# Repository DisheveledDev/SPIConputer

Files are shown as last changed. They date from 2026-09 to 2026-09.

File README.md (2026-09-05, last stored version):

# SPIConputer (working title)

> A retro computer whose system bus is SPI. Every peripheral is an
> autonomous node with its own microcontroller; the main CPU sends it a
> command and the node carries it out without further CPU involvement.

## Status

Design phase. Nothing is built yet. This README is the living design
document: decisions go in the [Decision log](#decision-log), unresolved
items live in [Open questions](#open-questions).

## Concept

- **Bus = SPI.** SCK, MOSI and MISO are shared across all nodes; each
  node gets its own chip-select (SS) line from the main CPU.
- **Autonomous peripherals.** Each node (video, storage, IO, sound,
  console) has its own MCU (ATmega328 or similar). The main CPU issues
  high-level commands ("draw this sprite", "read sector N", "play this
  note") and moves on. Nodes report completion asynchronously.
- **C64 form factor.** The board fits inside a Commodore 64 shell,
  reusing its keyboard and (ideally) its port cutouts.

## Architecture overview

```
                                  +----------------------+
                                  |  MAIN CPU (master)   |
                                  |  MCU: TBD            |
                                  +--+--+--+--+--+--+----+
                                     |  |  |  |  |  |
        Bus: SCK + MOSI + MISO shared; one SS per node; IRQ per node (TBD)
                                     |  |  |  |  |  |
        +----------------------------+  |  |  |  |  +--------------------------+
        |                               |  |  |  |                             |
  +-----+--------+              +-------+  |  |  +-------+             +-------+--------+
  | VIDEO NODE   |              | IO NODE |  |  | STORAGE |             | SOUND NODE     |
  | ATmega2560   |              | ATmega  |  |  | NODE    |             | ATmega328 (TBD)|
  +-----+--------+              +---+-----+  |  +----+----+             +-------+--------+
        |                           |        |       |                         |
  2nd SPI -> Flash           C64 keyboard    |   SD card (SPI)           Audio out (TBD)
  (tile/glyph data)          Joystick x2     |
        |                           |        |
       VGA (DB15)                   |        |
                                    |   +----+--------+
                                    |   | CONSOLE NODE |
                                    |   | RS232 / TBD  |
                                    |   +-------------+
                                    |
                          +---------+---------+
                          | EXPANSION (SDI)   |
                          | bus passthrough   |
                          +-------------------+
```

## System bus

### Signals

| Signal | Direction | Notes |
| --- | --- | ----- |
| SCK | master -> all | Bus clock |
| MOSI | master -> all | Master out, slave in |
| MISO | all -> master | Shared; slaves tri-state when not selected |
| SS_n | master -> one node each | Dedicated chip-select per node |
| IRQ_n  | node -> master | Async completion signal (scheme TBD) |

### Protocol (proposal, unverified)

- Every transaction: master asserts the node's SS, sends a 1-byte
  command, an optional length byte, then payload. The slave responds
  with status byte(s) in the same transfer.
- Each node exposes a small **register map**: writing a command
  register starts an autonomous operation; a status register reports
  idle/busy/done/error; data registers move payloads.
- Completion: node asserts IRQ_n when done (or master polls status).
  See [Open questions](#open-questions).

### Timing and electrical gotchas

- **Slave clock limit:** on classic AVRs, SPI *slave* mode tops out at
  Fosc/4 (4 MHz at 16 MHz Fosc) even though *master* mode can run at
  Fosc/2 (8 MHz). The bus clock is therefore realistically **4 MHz**
  unless a node runs a faster crystal or a different SPI peripheral.
- **Shared MISO:** AVR SPI hardware tri-states MISO while SS is
  deasserted, which is what makes the shared bus work. Firmware must
  keep the SPI peripheral in slave mode; don't reuse MISO as a GPIO
  output.
- **Master SS pin:** in AVR SPI master mode the SS pin must be an
  output (or held high) or the master's own SPI can drop into slave
  mode on a false edge.
- Keep traces short; bus speed is modest but the bus crosses multiple
  boards/connectors.

## Nodes

### Main CPU (master)

- MCU: **TBD**. Candidates: ATmega2560 (fits the all-AVR theme and has
  enough pins for per-node SS + IRQ), or something bigger.
- Owns the bus, dispatches commands, runs the OS/shell/BASIC.
- Needs enough GPIO for: one SS per node, one IRQ per node, any
  console-side RS232 if not handled by a node.

### Video node

- MCU: **ATmega2560-16AU** (specified).
- Output: **VGA via DB15** (rear panel).
- Rendering: **text/sprite system**. Tile map and sprite list live in
  SRAM; tile/glyph bitmaps live in an external **SPI flash** on a
  *second* SPI bus (separate from the system bus).
- Firmware renders scanlines, not a CPU-driven framebuffer.

**Timing budget** (this constrains every video decision):

- Pixel clock comes from an AVR shift register (SPI/USART in master
  mode) = Fosc/2 = **8 MHz** at 16 MHz Fosc.
- One VGA line (31.78 µs) = ~254 pixel clocks at 8 MHz, so visible
  width is roughly **160-250 px** at 1 bit per pixel, packed 8 px per
  byte (~25-30 bytes per line, ~1 µs per byte shifted out).
- Flash reads also max out at ~1 byte/µs (8 MHz SPI). Fetching tile
  data on the fly leaves zero slack, so glyphs/tile rows must be
  **cached into SRAM during blanking** (8 KB SRAM on the 2560).
- Resolutions, colour depth (e.g. 3-bit RGB via 3 pins vs. resistor
  DAC) and sprite count are all [open questions](#open-questions).

### IO node

- MCU: ATmega328 or similar.
- Drives the **C64 keyboard** (8x8 matrix, needs 16 GPIOs + pull-ups)
  via the internal connector, and two **DB9 joystick ports**
  (Atari/C64 standard: 4 directions + fire, active-low, pulled high).
- Scans/debounces locally; the main CPU reads key/joystick *events*,
  not raw matrix state.

### Storage node

- MCU: ATmega328 or similar.
- **SD card in SPI mode** (rear panel slot).
- Exposes block read/write; FAT layer either here or on the main CPU.
- Gotcha: SD cards are **3.3 V logic** — the node needs a 3.3 V rail
  (LDO) and level shifting on MOSI/SCK/SS (MISO can usually feed 5 V
  inputs directly through a divider). Classic AVRs are 5 V parts.

### Console node

- **RS232** serial console (rear panel, DB9).
- Open: true RS232 levels (needs a MAX232-style transceiver) vs. TTL
  serial vs. USB (FTDI/CH340). This node may end up merged into the IO
  node.

### Sound node

- MCU: ATmega328 or similar (TBD).
- Receives note/effect commands and generates audio autonomously;
  output via PWM + RC filter, then amp/jack (TBD).
- Open: chiptune-style synth, sample playback, or a SID-inspired voice
  set.

### Expansion (SDI)

- Rear-panel expansion connector. Intended as a passthrough of the
  system bus (SCK/MOSI/MISO + an SS/IRQ pair + power) so new nodes can
  hang off the bus.
- **"SDI" needs defining** — see [Open questions](#open-questions).

## Connectors

| Connector | Location | Standard / notes |
| --- | --- | --- |
| VGA | rear | DB15, driven by video node |
| Console | rear | DB9 RS232 (or USB) — TBD |
| Expansion | rear | SDI — bus passthrough, pinout TBD |
| SD card | rear/side | microSD slot, SPI mode |
| Joystick x2 | rear/side | DB9, Atari/C64 standard |
| Keyboard  | internal | C64 keyboard connector, matrix scan by IO node |
| Power | rear | 5 V barrel jack — TBD |

## Form factor

- Board must fit a **C64 shell**; port cutouts should line up with the
  case openings. Open: which C64 revision (breadbin vs. 64C) — they
  have different keyboard connectors and cutouts.

## Power

- Single **5 V** rail for all nodes; local 3.3 V LDO on the storage
  node (and anywhere else 3.3 V logic appears). Total draw is small
  (a handful of AVRs + flash + SD), but budget should be verified once
  nodes are prototyped.

## Firmware conventions (proposed)

- Every node: **command loop** — SPI slave ISR receives command frames,
  main loop executes the current task, sets status, raises IRQ.
- Shared node firmware skeleton/library would avoid re-implementing the
  bus layer per node (TBD once toolchain is chosen).
- Each board exposes an **ICSP/ISP header** for initial programming
  and bootloader flashing.

## Development tooling

TBD. Candidates: avr-gcc + avrdude directly, PlatformIO, or Arduino
CLI. Decide in the [Decision log](#decision-log) and document the
canonical build/flash commands here once real code exists.

## Decision log

| # | Decision | Rationale | Date |
| - | --- | --- | ---- |
| | *(none yet)* |  |  |

## Open questions

1. **Main CPU** — which MCU drives the bus and runs the OS?
2. **Bus protocol** — exact command framing; register-map layout per
   node; IRQ scheme (one line per node vs. shared open-collector).
3. **Video modes** — target resolution(s), colour depth, sprite count,
   tile cache strategy within the 8 MHz pixel-clock budget.
4. **SDI definition** — what exactly does the expansion connector
   carry, and what can plug into it?
5. **Sound architecture** — synth vs. samples, voice count, output
   stage (amp, jack on case?).
6. **Console** — true RS232 levels, TTL, or USB?
7. **C64 case revision** — breadbin or 64C (keyboard connector,
   cutouts, mounting holes differ).
8. **Toolchain** — avr-gcc / PlatformIO / Arduino, and the flash
   workflow for each node.
9. **Firmware framework** — shared bus-layer library across nodes, or
   per-node implementations?

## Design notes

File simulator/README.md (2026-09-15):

# SPIComputer OS — Desktop Simulator

Lives next to `system/` (it is not part of the system itself).
Runs the real OS C code on macOS with the hardware layers replaced by
desktop implementations, so programs can be developed and tested without
the board:

| OS component | Simulator replacement |
|---|---|
| Core 0 FatFs / SD card (`fs_core0.c`) | `sim_fs.c`: a real host folder (default `./sdcard`) via stdio/POSIX |
| Core 0 HSTX/HDMI rendering | `render_line()` → RGB24 texture in an SDL window |
| Core 0 HDMI audio islands | `audio_mix()` → `SDL_QueueAudio` at 44.1 kHz stereo |
| Keyboard matrix / joysticks | SDL keyboard + game controllers → `input_event_t` queue |
| Two cores | one thread: scheduler steps with the RPC serviced inline |

The Lua core, process model, timers, input deposit, screen/sound/sys
modules, RPC transport and filesystem bridge are the actual OS sources
(the same ones the host tests exercise).

## Build & run

Requires SDL2. Run these commands from the folder that contains `system/`
and `simulator/`:

```bash
brew install sdl2
cmake -S simulator -B simulator/build
cmake --build simulator/build
./simulator/build/spicomputer_sim
```

On first run the simulator creates `sdcard/` **next to the simulator
binary** (e.g. `simulator/build/sdcard`) if it is missing, including the
protected `core/`, installed-app `apps/`, and writable `data/` directories.
Copy system programs into `core/`, applications into `apps/`, and user files
into `data/`. Basing it on the executable keeps it the same folder however
you launch the simulator; `--sdcard DIR` points it elsewhere.

With a `boot.lua` or `boot.prg` that starts the shell you land at the SPIOS
`READY.` prompt; `--boot <program>` boots a source or compiled program directly instead.

## Controls

| Input | Sends |
|---|---|
| Letters, digits, punctuation, Return, Tab, Backspace, Escape, Delete | ASCII key events (shift-aware) |
| Arrow keys, Home, F1–F7 | extended C64 key codes (`INPUT_KEY_*`) |
| F8 | RESTORE modifier |
| F9 | RUN/STOP |
| Left Alt | Commodore (C=) modifier |
| Numpad 8/2/4/6, 0 | joystick 1 (up/left/right/down, fire) |
| Game controllers | joystick 1 and 2 (d-pad + A/B fire) |

The simulator window is resizable. Its 640x480 output is always presented at
4:3, with letterboxing when the window shape is wider or taller. This makes
80-column text readable at larger window sizes without changing the logical
screen geometry.

## Options

```
--sdcard DIR        virtual SD card folder (default: <simulator dir>/sdcard)
--boot FILE         program to boot (default: core/boot.lua)
--ticks N           at most N scheduler ticks per frame (default: 64)
--dump-frame FILE   write the final 640x480 frame as a PPM
--dump-text FILE    write the final text screen (40x30, or 80x60 in modes 2/3), overlay
                    on top, '#' for non-ASCII codes, '|' then '^' under inverted cells
--wav FILE          headless: write the run's mixed audio as a 44.1 kHz stereo WAV
                    (one 60 Hz frame of samples per simulator frame)
--check FILE        compile FILE with the OS Lua and exit
--compile IN OUT    compile Lua source IN to a .prg binary chunk and exit
--strip             with --compile: leave out debug info (line numbers, local
                    names); the loaded program needs about a fifth less heap,
                    but its runtime errors carry no line numbers
--headless          no window/audio (smoke tests, CI)
--exit-after-ms N   quit automatically after N ms
--type TEXT         scripted keystrokes, one per frame (\n Return, \t Tab,
                    \e Esc, \u \d \l \r cursor keys, \1..\7 F1..F7, \w a
                    half-second pause, \\ backslash)
--type-delay-ms N   wait N ms after start before typing (default 500;
                    use ~3500 to type into the shell after the boot splash)
```

`--headless --exit-after-ms 1500` boots the OS, runs the scheduler and
the RPC, prints a summary and exits 0 — useful as a smoke test.
`--boot apps/foo.prg` starts a program directly instead of
`core/boot.lua` (the IDE uses this to run a project straight from its
folder, and `--boot core/os.prg` skips straight to the shell).
`--dump-frame shot.ppm` captures the last rendered frame for inspection
(convert with `sips -s format png shot.ppm --out shot.png`).

## Working on programs

Programs are ordinary files in `sdcard/`; source programs use `.lua` and
compiled Lua chunks use `.prg`. A program is loaded when launched (`run
foo` from a shell, or just `foo`), with the compiled `.prg` preferred when
both forms exist. Use `--compile source.lua output.prg` to create a chunk;
changes are picked up on the next launch;
`boot.lua` is read at startup. A program that saves files writes
straight back into the folder. In this workspace the card programs are
SPIEdit projects under `software/`; their builds (`software/*.lua`) are
what you copy into `sdcard/`.

## Behaviour notes

- Each rendered frame runs up to `--ticks` scheduler steps (default 64)
  and ends early when the 60 Hz frame clock moves on, so a program that
  paces its `tick()` with `WaitVSync()` gets one step per frame and every
  frame is drawn and has its input read. The exit summary reports both
  `ticks` and `frames`. Programs should compute elapsed time from
  `TimeNow()` as on hardware.
- Audio is mixed on the main thread and queued: the pump tops the SDL
  queue up to ~40 ms every frame and while waiting for the next frame
  boundary, the same single-producer shape as core 0.
- Hardware output files are not compiled in; the SDL window replaces the
  hardware display.
- macOS key repeat is passed through as repeated key-down events.

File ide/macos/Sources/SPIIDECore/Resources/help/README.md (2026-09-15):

# Help documents

The IDE's help panel (right-click a name in the editor, or search the
panel) reads every `*.json` file in this folder. The three shipped are:

- `lua.json` — Lua 5.5 keywords, base functions and the modules the OS
  opens for programs (string, table, math, coroutine, utf8, package).
- `os.json` — the SPIComputer OS API: program contract, system calls,
  display, sound, `fs`.
- `sdk.json` — the frameworks (`Screen`/`Attributes`, `Overlay`, `Text`,
  `Timer`, `Sound`/`Music`, `Input`): namespaces, constants and every
  function. Constants are the column-0 `Name.CONST = value` lines of a
  framework's preamble; each needs an entry of kind `constant`.

**This folder is the documentation of record for the IDE.** When you add
or change an API call, a framework function or a Lua facility that
programs can use, update the matching entry here in the same change:
`HelpLibraryTests` fails when an OS API function or a framework function
has no entry, or when a framework entry's signature no longer matches
the `---` line above the function in `Resources/sdk/*.lua`.

## Schema

```json
{
  "source": "os",                 // lua | os | sdk (any string; groups the panel's source badge)
  "title": "SPIComputer OS API",
  "entries": [
    {
      "name": "Screen.OutText",          // the name as written at a call site; methods start with ":" (":read")
      "kind": "function",                // function | method | namespace | module | constant | keyword
      "group": "Screen",                 // heading the entry is listed under
      "framework": "screen",             // sdk entries only: the framework id
      "signature": "Screen.OutText(x, y, text [, attr])",
      "summary": "One line, shown in lists and at the top of the panel.",
      "description": "As many sentences as it takes: behaviour, limits, gotchas.",
      "parameters": [
        { "name": "x", "type": "number", "optional": false, "description": "column 0-39" }
      ],
      "returns": "true, or nil, err",
      "example": "Screen.OutText(2, 5, \"Hello\", 0x02)",
      "seeAlso": ["Screen.CenterText", "ScreenWrite"]
    }
  ]
}
```

Every field except `name`, `kind` and `signature` may be empty or
omitted. `seeAlso` names other entries (any file); the panel links them.
Keep examples short and real: something a program would actually write.

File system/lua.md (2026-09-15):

# Lua API Reference — SPIComputer OS

The contract between OS programs and the runtime. This document is the
single reference for app developers and for the (future) IDE; keep it in
sync with the implementation (`sys_lua.c`, `fs_lua.c`, `program.c`).
Anything not listed here is not part of the supported API.

## Program Structure

A program is a Lua source file or compiled `.prg` bytecode file on the SD
card. The file body runs once at launch and must only **define** the entry
points (plus any local state);
it must not block or run the main logic:

```lua
-- myprog.lua
local ticks = 0            -- program-local state persists between ticks

function setup()           -- optional: called once when the program starts
    print("hello")
end

function tick()            -- called repeatedly, as fast as possible
    ticks = ticks + 1
end

function finish()          -- optional: called when the program exits
    print("goodbye")
end
```

Semantics:

- `setup()` is called once, before the first `tick()`.
- `tick()` runs free-running (no arguments, no dt; use `TimeNow()` to
  compute elapsed time yourself). One scheduler step runs either due
  timer callbacks **or** one `tick()` — they never overlap or re-enter.
- `finish()` runs when the program exits (see `ExitProgram()`).
- If `setup()` throws, the program never starts and `Launch()` reports
  the error to its caller.
- If `tick()` or a timer callback throws, the error is printed and the
  program is terminated (after `finish()`); the program that launched it
  resumes on its next tick.
- `print()` goes to the standard output (serial/USB console).
- A global `pid` (number) is set at launch, plus `Pid()`.

## OS Functions

Available as globals in every program.

### Time and process

| Function | Returns |
|---|---|
| `TimeNow()` | milliseconds since boot (monotonic) |
| `Pid()` | this program's pid (number) |
| `ExitProgram()` | nothing; asks the OS to exit after the current tick/timer callback returns |
| `Launch(path [, arg [, replace]])` | `true`, or `nil, err` on failure (missing file, Lua error in body/setup, too many programs, out of memory). `arg` (a string) is passed to the program chunk as its first vararg: `local filename = ...`. With `replace` true the caller leaves the program stack on its way out (see below) |
| `Execute(path, arg1, ...)` | `true`, or `nil, err`; runs a program file in the foreground with up to 16 string arguments |
| `ExecuteString(source, arg1, ...)` | `true`, or `nil, err`; compiles and runs a Lua source string the same way |
| `Compile(src [, dst])` | `true, bytes`, or `nil, err` (missing file, syntax error with line, write failure); compiles the Lua source file `src` on the card into a `.prg` binary chunk, the same format the IDE builds and `Launch`/`Execute`/`dofile`/`require` load. `dst` defaults to `src` with `.lua` replaced by `.prg`. Paths are program-relative like the `fs` module's. The parser runs outside the caller's heap cap |
| `UtilityResult(ok, message)` | ends the program with a result for its caller: every utility does; an interactive program may (a picker returning a choice) |
| `UtilityPoll()` | `ok, message`, or `nil`; retrieves the result of a child that ended with `UtilityResult` |

Launch/Execute semantics: on success the new program runs on top of
the stack and the caller stops being scheduled until it exits. The call
itself **returns immediately** (the caller's Lua resumes right away, with
the child's video/audio current), so nothing may follow the call except
returning from the current `tick()`; code that must run *after* the
child exits belongs in the caller's next `tick()`, which only happens
once the child has gone:

`Launch(path, arg, true)` replaces the caller instead of stacking on it:
the new program takes the caller's place (the caller's parent becomes its
parent) and the caller leaves the stack. Its Lua state, timers and audio
state are released once the call that launched it has returned, so a boot
loader can hand the machine to the shell without staying resident. The
caller's `finish()` still runs during that release.

```lua
local child_running = false

function tick()
    if child_running then
        -- We only tick again after the child exited.
        child_running = false
        print("the program finished")
        return
    end
    if some_condition then
        child_running = true
        Execute("child.lua", "arg")
    end
end
```

Arguments: every program (booted, launched or executed) gets a global
`args` table with the arguments as strings, `args[1]` first (`#args` is
the count). `args[1]` is also passed to the chunk as its first vararg,
so `local filename = ...` keeps working.

Noninteractive utilities set `__spi_interactive = false` in their generated
program. They run in an isolated Lua state but do not allocate or replace a
video/audio state. They call `UtilityResult(ok, value)` once, where `value`
is a string or a table (strings, numbers, booleans and nested tables with
string or integer keys survive the crossing; anything else becomes nil;
8 KB at most); the launching program receives `ok, value` through
`UtilityPoll()` after the utility exits, the table rebuilt directly in its
own state (no Lua compile, so a near-limit result costs the caller little
more than its strings). Installed in `utils/` as `name.util`, a utility
is a shell command: `HELLO one two` runs `utils/hello.util` with
`args = {"one", "two"}`. Keys typed while a utility runs go to the
interactive program below it (the shell's type-ahead), not to the utility.

An interactive program may end with `UtilityResult` too: its parent gets
the value the same way (a program that just exits leaves nothing to
poll). The APPS launcher (`core/apps.prg`) uses this to hand its choice
back to the shell.

The shell prints a result table's `message` first, then its `lines`
array in order, then every other field as `KEY = VALUE`; long output
stops at `-- MORE --`. A table with a `run` field (`{ run = path, kind =
"application"|"game"|"utility", args = {...} }`) is instead run by the
shell as if typed, so a game started that way still replaces the shell.

Shell arguments: words that name an existing data entry, or look like a
file name (only name characters, a letter, and a slash or an extension:
`notes.txt`, `games/x`), arrive as full card paths (`/data/...`);
unquoted words with `*` or `?` expand to the matching entries' paths;
options (`-n`), numbers (`2.5`, `1/3`), expressions and `"quoted words"`
arrive exactly as typed. `command > file` / `>> file` sends a built-in's
or utility's output to a file; `/data/autoexec.txt` runs at start-up.

Games are the other special kind: launched with `Launch(path, arg, true)`
by the shell, so the shell's state is released and the game has the
machine to itself. When the last program on the stack exits (a game, or
the shell itself) the device restarts (the simulator boots again), so a
game ends with `ExitProgram()` and never returns to a shell.

Every program also receives an `app` table with `app.root`, `app.program`,
`app.metadata`, and `app.resources` paths when launched from an `.app`
directory.

### Timers

| Function | Returns |
|---|---|
| `TimerCreate(fn, interval_ms [, oneshot])` | timer id (>= 1), or raises an error if the program has too many timers |
| `TimerStop(id)` | `true` if the timer existed and was stopped |

- `fn` takes no arguments; it runs in the program's own state.
- Minimum interval is 1 ms.
- `oneshot` defaults to `false` (repeating).
- Deadlines are absolute; while the program is paused (another program
  on top) its timers pause too, and deadlines shift by the pause
  duration on resume (no catch-up bursts).
- Maximum 8 timers per program.

### Input

| Function | Returns |
|---|---|
| `InputPoll()` | the next pending input event as a table, or `nil` when none |
| `InputControl(n)` | current joystick state for controller `n` (1 or 2) as `{up=, down=, left=, right=, fire=}` (booleans), or `nil` for invalid `n` |
| `WaitVSync([ms])` | frames elapsed since this program's previous `WaitVSync` (blocking up to `ms`, default 100, for the next frame) |

Event table shape:

```lua
{ type = "key" | "control1" | "control2",
  key = <number>,      -- ASCII code, or extended code (see below)
  mods = <number>,     -- bitmask of modifiers held
  pressed = 0 | 1,     -- 1 = down, 0 = up
  ctrl = <number>,     -- controller number for control events
  dirs = <number> }    -- bitmask of changed direction(s) for control events
```

Typical reading pattern inside `tick()`:

```lua
while true do
    local ev = InputPoll()
    if not ev then break end
    if ev.type == "key" and ev.pressed == 1 then
        if ev.key == 13 then ... end          -- Return
    end
end
```

Key codes:

- Printable keys carry their ASCII code (letters arrive lowercase
  unshifted, uppercase when Shift is held — the shift is already applied
  to `key`; `mods` also records it).
- Control keys: Return = 13, Tab = 9, Backspace = 8, Delete = 127,
  Escape = 27, Ctrl+letter = 1-26.
- Keys with no ASCII code use the extended codes:

| Code | Key |
|---|---|
| 128 | Cursor up |
| 129 | Cursor down |
| 130 | Cursor left |
| 131 | Cursor right |
| 132-138 | F1-F7 |
| 139 | Home |
| 140 | Run/Stop |

- Modifier bits (`mods`): SHIFT = 1, CTRL = 2, C= = 4, RESTORE = 8.
  Modifier key presses also arrive as events with `key = 0` and the
  modifier bit in `mods`.
- Joystick direction bits (`dirs`): UP = 1, DOWN = 2, LEFT = 4,
  RIGHT = 8, FIRE = 16. One event per direction edge.

### Frame synchronisation

`WaitVSync([ms])` returns the number of video frames that arrived since
this program's previous `WaitVSync` (the first call measures from program
start). With no argument it waits up to 100 ms for a frame; with `ms` it
waits up to that long; `WaitVSync(0)` polls once and returns immediately,
which suits programs that already run from a timer.

```lua
function tick()
    WaitVSync()          -- pace the tick to the 60 Hz display
    ...                  -- draw the next frame
end
```

On hardware without a display (dev boards, or a stalled scanout) the call
simply times out and returns 0, so programs must not assume frames always
advance.

### Optional input callbacks

Instead of (or as well as) polling, a program may define these globals:
the scheduler invokes them as events arrive, before the next `tick()`,
with the same error handling as `tick()` (a throwing callback terminates
the program). They are looked up by name for every event, so a program
(or a framework such as `Input.Keyboard.Callback`) may define, replace
or remove them at any time, including from `setup()`:

```lua
function on_keypress(key, shift, ctrl, cbm, restore)
    -- key-down events only (key ~= 0); releases still arrive via InputPoll
end

function on_control(index, up, down, left, right, fire)
    -- every joystick change, with the full stick state after the event;
    -- index is the port: 0 = joystick 1, 1 = joystick 2
    -- (note InputControl(n) uses 1/2)
end
```

Events are placed in the program's ring either way, so a program using
callbacks can still poll `InputPoll()` when it needs key releases, raw
edges, or modifier-key events.

## Display (Screen API)

Available as globals; they operate on the program's own screen slot
(restored automatically when the program resumes after a launch). Calls
are queued to the display core and applied at the next frame boundary
(50 Hz), so a change becomes visible on the following frame; a program
that queues faster than a frame's worth of changes is briefly blocked.

### Screen modes

| Mode | Geometry | Type | Colour |
|---|---|---|---|
| 0 | 40x30 tiles | 8x8 tiles + attribute map | B&W (invert attr applies) |
| 1 | 40x30 tiles | 8x8 tiles + attribute map | per-cell invert + 7 colours |
| 2 | 80x60 tiles | 8x8 tiles + attribute map | B&W (invert attr applies) |
| 3 | 80x60 tiles | 8x8 tiles + attribute map | per-cell invert + 7 colours |
| 10 | 320x240 | direct pixels (one byte each) | 256-entry palette |
| 11 | 160x120 | direct pixels (one byte each, shown 4x4) | 256-entry palette |

Output is always 640x480 at 60 Hz. Modes 0, 1 and 10 are 320x240
logically and scaled 2x; modes 2 and 3 draw their 8x8 cells 1:1 at the
full resolution (twice the cells per row, every output line rendered),
so they cost the display core about four times the rendering per line:
use them for text screens, not for animation. Every cell call
(`ScreenOut`, the block ops, the `Screen`/`Overlay` frameworks) takes
coordinates in the geometry of the mode the program selected, and
`Screen.Mode` updates `Screen.COLS`/`ROWS` and `Overlay.COLS`/`ROWS`.
The pixel modes are a plain byte buffer, one palette index per pixel
(mode 11's 19 KB buffer is the cheapest to draw and to display). They
have no text cells: `ScreenOut` and the block ops fail there, and text is
drawn as pixels with `ScreenPixelText`. Every pixel call is one display
op clipped by the display core, so shapes, sprites and text may run off
the edges. The default palette is 0-15 the text colours, 16-231 a 6x6x6
colour cube (16 + 36r + 6g + b, each 0-5), 232-255 a grey ramp;
`ScreenPalette` changes any entry. The Graphics framework (sprites with
rotation, flips and scaling, text, scrolling) is Lua over these calls.
The RP2040 dev board supports modes 0 and 1 only.

### Functions

| Function | Returns |
|---|---|
| `ScreenMode(mode)` | `true`, or `nil, err` (invalid mode, unsupported board) |
| `ScreenOut(x, y, char [, attr])` | `true`, or `nil, err` (text modes); draws on the base layer |
| `ScreenAttr(x, y, flags)` | `true`, or `nil, err` |
| `ScreenDefineTile(index, bytes)` | `true` (bytes = table of 8 row patterns or 8-byte string; bit 0 of a row is the leftmost pixel) |
| `ScreenPalette(i, r, g, b)` | `true` |
| `ScreenPaletteSet(t)` | `true` (t = array of `{r,g,b}` tables or 0xRRGGBB integers, up to 256) |
| `ScreenClear([char])` | `true` (defaults to space); clears the base layer |
| `ScreenBox(x, y, w, h [, style [, attr]])` | `true`, or `nil, err`; draws a frame with the ROM box-drawing characters (style 1 = single line, default; 2 = double). Needs `w` and `h` >= 2; clipped at the screen edge |
| `ScreenFill(x, y, w, h [, char [, attr]])` | `true`, or `nil, err`; writes `char` (default space) and `attr` into every cell of the rectangle; clipped at the screen edge |
| `ScreenFillAttr(x, y, w, h, attr)` | `true`, or `nil, err`; sets the attribute of every cell in the rectangle, characters unchanged |
| `ScreenWrite(x, y, text [, attr])` | `true`, or `nil, err`; writes the bytes of `text` as consecutive cells from (x, y), wrapping to the next row (so `ScreenWrite(0, 0, map)` with a 1200-byte string replaces the whole screen); with `attr`, every cell gets it too |
| `ScreenWriteAttr(x, y, attrs)` | `true`, or `nil, err`; the bytes of `attrs` become the attributes of consecutive cells from (x, y) |
| `ScreenCopy(sx, sy, w, h, dx, dy)` | `true`, or `nil, err`; copies a block (characters and attributes) so its top-left lands at (dx, dy); clipped so both fit |
| `ScreenMove(sx, sy, w, h, dx, dy [, char [, attr]])` | as `ScreenCopy`, then blanks the part of the source the block no longer covers with `char` (default space) and `attr` |
| `ScreenScroll(x, y, w, h, dx, dy [, char [, attr]])` | `true`, or `nil, err`; shifts the region's contents by (dx, dy) cells (negative = up/left); the cells uncovered get `char` and `attr` |
| `ScreenLoadImage(path, x, y [, w, h])` | reserved: always `nil, err` for now (the loader is not implemented) |
| `OverlayOut(x, y, char [, attr])` | `true`, or `nil, err` (text modes); draws on the overlay layer |
| `OverlayAttr(x, y, flags)` | `true`, or `nil, err` |
| `OverlayClear([char])` | `true` (defaults to space); blanks the overlay and hides it |
| `OverlayBox`, `OverlayFill`, `OverlayFillAttr`, `OverlayWrite`, `OverlayWriteAttr`, `OverlayCopy`, `OverlayMove`, `OverlayScroll` | as the `Screen` versions, on the overlay layer (a dialog over the base: `OverlayFill` the body, `OverlayBox` the frame, `OverlayWrite` the text; `OverlayClear` removes it) |
| `ScreenPlot(x, y, colour)` | `true`, or `nil, err` (modes 10 and 11) |
| `ScreenPixelRect(x, y, w, h, colour [, filled])` | `true`, or `nil, err`; a rectangle outline, or filled |
| `ScreenPixelLine(x0, y0, x1, y1, colour)` | `true`, or `nil, err`; a line, both ends included |
| `ScreenPixelCircle(cx, cy, r, colour [, filled])` | `true`, or `nil, err`; a circle outline, or a disc (r <= 1024) |
| `ScreenPixelScroll(x, y, w, h, dx, dy [, fill])` | `true`, or `nil, err`; shifts a region's pixels by (dx, dy), -127..127; uncovered pixels get `fill` |
| `ScreenBlit(x, y, w, h, pixels [, key])` | `true`, or `nil, err`; w*h palette bytes row by row to (x, y), pixels equal to `key` skipped; at most 8184 pixels a call |
| `ScreenPixelText(x, y, text, colour [, bg [, scale]])` | `true`, or `nil, err`; 8x8 font (or the program's tiles) as pixels, `scale` 1-4, cells painted `bg` when given; 64 characters a call |

The block calls (`Box`, `Fill`, `FillAttr`, `Write`, `WriteAttr`, `Copy`,
`Move`, `Scroll`) each queue **one** display op whatever the size of the
rectangle; the display core does the work at the frame boundary. Prefer
them to loops of `ScreenOut`: a full-screen repaint is one `ScreenWrite`
instead of 1200 ops. They are text-mode calls; the pixel modes have the
`ScreenPixel*`, `ScreenBlit` and `ScreenPlot` calls, one op each too.

### Frameworks

The IDE can inject read-only frameworks (SDKs) into a program: `Screen`,
`Overlay`, `Text`, `Timer`, `Sound`/`Music` and `Input` namespaces with
higher-level calls such as `Screen.CenterText(y, text)`,
`Screen.Move(x1, y1, x2, y2, x3, y3)`, `Overlay.Dialog(title, lines)`,
`Text.Wrap(s, width)`, `Timer.Every(ms, fn)` (returning an object with
`Cancel`/`Pause`/`Resume`), `Sound.Tone(hz, ms)` and
`Input.Keyboard.Callback(key, fn)`, and `Graphics` (sprites, shapes and
text on the pixel modes: `Graphics.Sprite`, `s:MoveTo`, `s:Turn`,
`Graphics.Text`). They are plain Lua over the API above,
selected per project in the IDE's settings, and stripped at build time to
the functions the program uses. The framework sources (and their
documentation) are `ide/macos/Sources/SPIIDECore/Resources/sdk/*.lua`.
The Screen framework also defines the `Attributes` namespace: the colours
by name (`Attributes.White`/`Red`/`Cyan`/`Purple`/`Green`/`Blue`/`Yellow`/
`Orange`, the mode-1 default palette) and `Attributes.Inverse`, to be added
for an `attr` argument (`Attributes.Red + Attributes.Inverse` is a red
block behind a space) without knowing the byte layout below.

Attribute byte: bit 7 = invert (swap fg/bg), bits 0-2 = colour index,
bit 6 = transparent overlay cell. Colour index `c` uses palette entry `c+1`
(so 0 = default white); the background is palette entry 0 (black). Text
modes have a base layer and one overlay layer. Overlay cells are hidden
until written: a cell shows when `OverlayOut`/`OverlayAttr` store an
attribute without bit 6, and `OverlayClear` hides the whole overlay
again. The renderer
composites a visible overlay cell over the base; hidden cells show the base.
Tiles not redefined render with the ROM font (ASCII-aligned, tile index =
character code). Tile rows and ROM font rows share one convention: bit 0 is
the leftmost pixel. A mode switch clears both layers; switching to mode 10
or 11 attaches the shared pixel buffer (only one pixel-mode program may
run; `Launch` from a pixel mode fails).

### ROM character set

The ROM font holds 256 glyphs laid out like CP437, so the codes match
the classic box-drawing references. Codes 32-126 are ASCII. The rest:

| Codes | Glyphs |
|---|---|
| 1, 2 | smiling faces (outline, filled) |
| 3, 4, 5, 6 | card suits: heart, diamond, club, spade |
| 7, 9 | bullet, hollow circle |
| 13, 14 | music notes (single, beamed) |
| 16, 17 | right / left pointer (menu cursor) |
| 24, 25, 26, 27 | arrows up, down, right, left; 18 = up/down, 29 = left/right |
| 30, 31 | triangles up, down (scroll indicators) |
| 28 | right angle |
| 174, 175 | `«` `»` |
| 176, 177, 178 | light, medium, dark shade |
| 179-218 | box drawing (single and double lines, all corners, tees and crosses; see below) |
| 219-223 | full block, lower half, left half, right half, upper half |
| 240-243 | `≡` `±` `≥` `≤` |
| 246-250 | `÷` `≈` `°` small bullet, middle dot |
| 253, 254 | `²`, filled square (checkbox) |

Box drawing codes (the ones `ScreenBox` uses in bold):

| | top-left | top-right | bottom-left | bottom-right | horizontal | vertical | cross |
|---|---|---|---|---|---|---|---|
| single | **218** | **191** | **192** | **217** | **196** | **179** | 197 |
| double | **201** | **187** | **200** | **188** | **205** | **186** | 206 |

Single-line tees: 195 `├`, 180 `┤`, 194 `┬`, 193 `┴`. Double-line tees:
204 `╠`, 185 `╣`, 203 `╦`, 202 `╩`. The mixed single/double joins
(181-184, 189, 190, 198, 199, 207-216) are at their CP437 codes too.
Every other code is blank until a program defines it with
`ScreenDefineTile`. Single lines are 2 px thick (matching the font's
stems) on rows/columns 3-4; double lines are 1 px on rows/columns 2 and
5, so adjacent cells join seamlessly.

## Sound and Music (Sound API)

Available as globals; they operate on the program's own audio state
(restored automatically when the program resumes after a launch). The
engine renders 8 score channels plus 8 sound-effect voices, stereo, at
44.1 kHz. The mix is designed to feed the HDMI audio data islands; that
backend is still to come, so audio is only audible under the simulator.
Screen updates are visible on the product board, which scans them out
over HSTX (see `WaitVSync` above).

### Sounds and samples

| Function | Returns |
|---|---|
| `SoundDefine(id, spec)` | `true`, or `nil, err` (id = 0..31) |
| `SoundPreset(name)` | a built-in sound's id (64+) and its spec table, or `nil, err` |
| `SoundPresets()` | the built-in bank: `{ {name=, effect=, id=}, ... }` |
| `SoundLoad(path [, root [, loop_start, loop_end]])` | sound id (32..39), or `nil, err`; `root` is the note recorded (default C4); a loop (frames) sustains a note |
| `SoundPlay(sound [, note [, dur_ms [, vol [, pan]]]])` | voice id (1..8), or `nil, err`; `sound` is an id or a built-in name |
| `SoundStop([voice])` | `true`/`false` (no argument: all one-shots) |
| `SoundStopAll()` | `true` (stops the score too) |
| `SoundVolume(v)` | `true` (master 0..255) |

`SoundDefine` spec: `wave` (`"square"`/`"pulse"`, `"triangle"`, `"saw"`,
`"sine"`, `"noise"`), `duty` (1..15, pulse width in 16ths), `attack`,
`decay`, `release` (ms, 0..255), `sustain` (level 0..255), `volume`
(0..255), `note` (the sound's own pitch, used when a play gives none),
and the pitch/tone effects: `slide` (semitones per second, -3200..3200;
a laser is -300, a jump +180), `vibrato` (depth in cents) with
`vibrato_rate` (Hz), `arp` and `arp2` (semitone steps applied every
`arp_ms` ms; `arp_loop = true` cycles 0, arp, arp2, else the steps are
taken once and held: a coin is `arp = 7, arp_ms = 60`), `cutoff` (a
low-pass tone, 255 open, lower darker). `base = "name"` starts from a
built-in sound and the other fields override it. All fields are
optional.

**The built-in bank.** Like the ROM font, the OS carries sounds a
program plays without defining anything, by name or by id 64 + index
(`audio_presets.c`): instruments, played at the note given (`lead`,
`pulse`, `bass`, `piano`, `organ`, `strings`, `flute`, `brass`, `bell`,
`pluck`, `chime`, `kick`, `snare`, `hihat`, `tom`, `clap`), and effects
that carry their own pitch (`coin`, `jump`, `laser`, `zap`, `explosion`,
`hit`, `hurt`, `powerup`, `blip`, `select`, `error`, `alarm`, `engine`,
`splash`, `bounce`, `teleport`). `SoundPlay("coin")` plays one;
`SoundPreset("laser")` returns its id and spec (change a field and
`SoundDefine` it under your own id, or use `base`).

`note` is a name (`"C4"` = middle C, `"A#3"`, `"Bb3"`, `"C-1"`..`"G9"`) or
a MIDI number 0..127 (default: the sound's own note, else C4). `dur_ms` holds the envelope before
release; omit/0 = one-shot (release after attack+decay). `vol` 0..255,
`pan` -64 (left) .. 63 (right).

`SoundLoad` parses a WAV file (PCM, 8/16-bit, mono/stereo, rate up to
48 kHz) from the SD card into the program's 64 KB sample pool and returns
a sound id (32+n) usable with `SoundPlay` and in scores. Samples play
pitch-shifted from their `root` note (the note recorded, default C4):
a bass sampled at C2 and loaded with `SoundLoad(path, "C2")` plays C2
at its recorded rate and every other note by the difference.

### Scores

| Function | Returns |
|---|---|
| `MusicDefine(name, spec)` | `true`, or `nil, err` |
| `MusicPlay(name [, loop])` | `true`, or `nil, err` |
| `MusicStop()` | `true` |
| `MusicPlaying()` | boolean |

`MusicDefine` spec: `loop` (default false) and `channels`, an array of up
to 8 channels, each an array of events:

```lua
MusicDefine("tune", {
  loop = true,
  channels = {
    { {at=0,   sound=0, note="C4", dur=200, vol=255, pan=0},
      {at=250, sound=0, note="E4", dur=200} },
    { {at=0,   sound=1, note="C2", dur=100} },
  },
})
MusicPlay("tune")
```

Event fields: `at` (ms from the start), `sound` (an id or a built-in
name, required), `note` (default: the sound's own note, else C4), `dur`
(ms; omit/0 = one-shot envelope), `vol` (0..255), `pan` (-64..63).
A channel may instead be a string of packed 10-byte records,
`string.pack("<I4BBI2Bb", at, sound_id, note, dur, vol, pan)` each, which
costs a few bytes of heap per note where a table costs a hundred. The
Sound framework's `Music.Track` writes a score as MML note strings
(`"o4 l8 c d e f g a b > c"`) per channel and compiles them to that.
Events may be written in any order (they are sorted per channel).
`MusicPlay` overrides the score's own `loop` when the second argument is
given.

### Modules

| Function | Returns |
|---|---|
| `ModLoad(path)` | `true`, or `nil, err`: a ProTracker `.mod` (4 channels, 31 samples), one per program |
| `ModPlay([loop])` | `true`, or `nil, err`; loops unless `loop` is false; stops a playing score |
| `ModStop()` / `ModPlaying()` / `ModUnload()` | as for scores |
| `ModPosition()` | `order, row, pattern`, or `nil` |
| `ModInfo()` | `{name, orders, patterns, samples, resident_kb, underruns}` |
| `ModChannels([t])` | a list of four `{sample, note, period, volume, level, active}` (`t` is refilled when given) |
| `ModRows(pattern [, from [, count]])` | rows of a pattern in RAM as `"C-2 05 C40 ..."` strings, or `nil, err` |
| `ModSamples()` | the 31 sample slots as `{name, length, volume, loop}` |
| `SoundSpectrum([t])` | ten band levels 0..255 of everything playing (`t` refilled when given) |
| `SoundSpectrumBands()` | the bands' centre frequencies: 60, 100, 160, 250, 400, 630, 1000, 1600, 2500, 4000 Hz |

A module streams from the card: the header, order list and two
patterns are in RAM; samples up to a 48 KB resident budget stay in RAM
(shortest first), the rest keep a 2 KB head so a note starts at once
and stream through 8 KB per-channel rings the OS core refills between
scheduler steps (a loop streams round without a break; one that fits
the ring is kept there). About 82 KB of system heap per loaded module,
which leaves the program itself around 65 KB of Lua heap on the device.
Effects 0-9, A-F and E1/2/5/6/9/A/B/C/D/E are played; the old
15-sample Soundtracker layout loads too; 6/8-channel modules are refused. A module with many long samples can outrun the
card: `ModInfo().underruns` counts the frames a sample was late for.

For visuals, `SoundSpectrum` is a ten-band analyser on the mixed output
(ten resonators fed one frame in four; each band a peak that decays over
about 50 ms), and `ModChannels` gives each module channel's note, sample
and a decaying level; `ModRows` formats pattern rows for a tracker view.
All three refill a table passed in, so a view polling every frame makes
no garbage. `MusicPlaying()` is true from the call to `MusicPlay` until the
score ends or `MusicStop`/`SoundStopAll`; a paused program is silenced
and resumes from its score position.

## The `fs` Module

SD card filesystem, loaded with `local fs = require("fs")`.

### File operations

| Function | Returns |
|---|---|
| `fs.open(path [, mode])` | file object, or `nil, err` |
| `fs.ls([path])` | array of `{name=, size=, dir=}` (default path `/`), or `nil, err` for a folder that does not exist |
| `fs.find(name [, path])` | the real entry name for a case-insensitive match (`fs.find("EDITOR.LUA")` -> `"editor.lua"`), or `nil` |
| `fs.stat(path)` | `{size=, dir=}`, or `nil, err` |
| `fs.exists(path)` | boolean |
| `fs.mkdir(path)` | `true`, or `nil, err` |
| `fs.remove(path)` | `true`, or `nil, err` |
| `fs.rename(old, new)` | `true`, or `nil, err` |
| `fs.free()` | `free_kb, total_kb` |
| `fs.ready()` | boolean (SD card mounted) |
| `fs.mount()` | boolean (re-mount attempt) |
| `fs.readall(path)` | whole file as a string, or `nil, err` (128 KB cap) |
| `fs.writeall(path, data)` | `true`, or `nil, err` |

Open modes: `"r"` read, `"w"` write (truncate), `"a"` append, `"+"`
upgrade to read+write. Default is `"r"`.

### File objects

| Method | Returns |
|---|---|
| `f:read(n)` | string (shorter than `n` at EOF) |
| `f:write(s)` | bytes written |
| `f:seek(offset [, "set"|"cur"|"end"])` | new position |
| `f:tell()` | position |
| `f:size()` | file size |
| `f:flush()` | `true` |
| `f:close()` | `true` |

Files are also closed automatically when garbage-collected or when the
program exits. Note: fs calls run synchronously on the OS core (they
used to be cross-core RPCs); a missing or ejected SD card produces
`nil, err`, never a crash.

## Loading Code from the SD Card

- `loadfile(path)` / `dofile(path)` — replaced with SD-backed versions;
  source files are compiled on the OS core and `.prg` files are loaded as Lua
  5.5 binary chunks.
- A `*.lua` load prefers the matching `*.prg` file when both are present.
  An explicit `*.prg` path is loaded directly.
- `require("name")` — an SD-backed searcher (slot 2) looks for
  `name`, `name.prg`, `name.lua`, `/name`, `/name.prg`, `/name.lua`,
  `/lib/name`, `/lib/name.prg`, `/lib/name.lua` in that order.

The standard Lua 5.5 libraries are available: base, coroutine, table,
string, math, utf8, package.

Relative filesystem paths are resolved against the program's inherited current
working directory. Programs receive that directory as `app.cwd`. An app's
resources are addressed relative to its bundle root, for example
`resources/help.txt` resolves inside `/apps/name.app/resources/`.

## Limits and Semantics

| Limit | Value |
|---|---|
| Program stack depth | 4 programs (including the shell) |
| Lua heap per program | 96 KB (allocation failure raises a Lua memory error, which terminates the program) |
| Script size | 128 KB |
| Timers per program | 8 |
| Pending input events per program | 128 (older events dropped) |
| Sound definitions per program | 32 |
| Scores per program | 8 (shared pool of 1024 events) |
| WAV sample pool per program | 64 KB (8 samples max) |

- `Launch()` from a program pauses it; input arriving while paused goes
  to whichever program is on top when the scheduler drains the queue
  (the topmost interactive one: a running utility has no keyboard).
- Programs cannot call each other's functions; each has its own
  `lua_State`. The only cross-program interaction is launch/exit.
- There is no `os.exit`/`os.time` style API — use `ExitProgram()` and
  `TimeNow()`.
- The shell (`os.lua`) is just another program (pid 0); it lives on the
  card, not in this repo.

## Not Yet Implemented

The HDMI audio data-island output backend (Phase 7): the HSTX video path
is live on the product board (RGB332 scanout, 640x480 at 50 Hz), but audio is
still simulator-only. Programs run fully in the simulator; the sound
engine itself is complete and host-tested meanwhile.

## Card Programs

The programs that run on the device are **not part of this repo**: they
are SPIEdit projects developed alongside it and copied onto the SD card
(the same way any other SPIComputer program is). The OS itself only
provides the runtime and this contract.

In this workspace those projects live in `software/` (`os`, `boot`,
`boot`, `apps` (the launcher), `editor`, `files`, `view`, `chars`, `keys`,
`bench`, `demo`, the utilities `dir`, `copy`, `del`, `ren`, `md`, `rd`,
`touch`, `stat`, `compile`, `help`, `wc`, `grep`, `find`, `tree`, `hexdump`,
`head`, `tail`, `sort`, `calc`, `sysinfo`, `hello`, and the games `breakout`,
`snake`, `spin`). Each builds into its own
`build/` folder; `software/install.sh [folder]` builds them all and
installs the products into a card image (default `software/sdcard/`,
ignored by git) laid out like the card. Copy that folder to a real card,
or point the IDE's Settings > SD card image at it.

The card layout separates the system, installed programs and user data:

- `core/` contains `boot.prg`/`boot.lua` and `os.prg`/`os.lua` (raw
  programs whose projects install to `core`). The shell cannot manipulate
  this directory.
- `apps/` contains applications as `name.app` directories: `app.prg`,
  `app.json`, an optional `icon.*` and `resources/`. `app.json` carries
  `name`, `version`, `description` (one line, set in the IDE's project
  settings), `type` (`application`, `utility` or `game`), `interactive`,
  `video`, `audio`, `entry` and `icon`. The shell's `APPS` picker lists
  apps and games by name and description; RETURN runs the selected one.
- `utils/` contains utilities as `name.util` directories (same contents).
  A utility is a shell command: typing its name runs it with the rest of
  the line as `args`, and its result table is printed.
- `games/` contains games as `name.game` directories. A game replaces the
  shell when launched and the device restarts when it exits.
- `data/` is the user area. `DIR`, `CD`, `MD`, `RD`, `DEL`, `REN`, `MOVE`,
  `COPY`, `TYPE`, `STAT` and `COMPILE` are restricted to this directory.
  Raw programs (`name.prg`/`name.lua`) here run by name.

At power-on firmware boots `core/boot.lua`, preferring `core/boot.prg` when
both exist. A command name resolves to `utils/`, then `apps/`, then
`games/`, then a `.prg`/`.lua` file in `apps/` or `data/`, compiled `.prg`
preferred. The simulator's `sdcard` folder is that
card; it creates `core/`, `apps/`, and `data/` when needed.
## Example

```lua
-- blink.lua: flashes a marker in the shell log every 500 ms until a
-- key is pressed.
local function log(msg)
    local f = fs.open("boot.log", "a")
    if f then f:write(msg) f:close() end
end

function setup()
    TimerCreate(function() log("blink\n") end, 500)
end

function tick()
    while InputPoll() do
        ExitProgram()
        return
    end
end

function finish()
    log("blink stopped\n")
end
```

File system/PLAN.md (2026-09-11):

# SPIComputer OS — Implementation Plan

Companion to `AGENTS.md` (design notes). This document breaks the design
into ordered phases with concrete tasks, acceptance criteria, and the
reasoning behind the main implementation decisions.

## Guiding Implementation Style

- **C11 only for all OS code.** No C++ in our code (the toolchain links
  with g++ only because the SDK enables CXX for `new_delete`; we stay C).
- **No RTOS, no dynamic allocation on core 0.** Core 0 is deterministic:
  static buffers, fixed tables, no malloc in hot paths. All heap activity
  lives on core 1 inside Lua's allocator.
- **Shared state is explicit and small.** One `system_state_t` struct
  describes everything shared across cores: video state (mode, map
  pointers, attributes, palette), input event queue, RPC queues. Every
  field has a documented access rule (owner, or guarded by which primitive).
- **Lock-free where possible, brief spinlocks otherwise.** Video map
  updates are pointer swaps (double-buffered) so no lock is ever held on
  the render path. Queues are single-producer/single-consumer with
  release/acquire atomics. The SDK's multicore-safe mutex/semaphore
  primitives are used only for rare, slow operations (mode changes, RPC
  completion).
- **Lua integration follows the existing `fs_lua.c` style:** one C file
  per module, registry metatables for objects, light validation, clear
  nil+error return convention. Never call Lua from core 0.
- **Everything compiles for two targets:** the RP2040 dev board (default,
  RS232-only) and the RP2354B product board. Platform `#ifdef`s switch pins
  and capabilities; unsupported features compile out entirely.
- **Host-testable.** Anything not touching registers (video state
  machine, renderer, Lua bridge, RPC protocol) gets a mock header and
  a host test in `tests/host/`, so bridge and renderer logic stays
  verifiable without hardware.

---

## Phase 0 — Foundations and Repo Hygiene

Goal: two working build targets, testable without hardware.

Tasks:
1. Install the ARM Cortex-M0+ toolchain (VS Code Pico extension) for the
   RP2040 dev build.
2. CMake restructure:
   - `CMakePresets.json` with two presets: `dev` (PICO_BOARD=pico,
     platform rp2040, serial stdio) and `product` (custom board header for
     RP2354B, platform rp2350, RISC-V toolchain, `PICO_FLASH_SIZE_BYTES=2MB`).
   - Split the monolithic `SPIComputerOS.c` into `core0/` and `core1/`
     translation units (still single binary, both cores in one image).
3. `board_config.h`: pin maps and capability macros behind
   `#if defined(PICO_RP2350)`; dev board = RS232 + SD only.
4. Move the scratch host test into `tests/host/` (mock `ff.h`, mock SD,
   test main exercising the Lua bridge) with a CMake host target.
5. Move SD pins on the product config to SPI1 GP8–11 (HSTX conflict).

Acceptance:
- `cmake --preset dev && cmake --build` produces a UF2 that boots on the
  RP2040 module, prints over RS232, mounts the SD card, runs `os.lua`.
- Host tests run and pass on the developer machine without hardware.
- Product preset configures cleanly (build may fail until Phase 1 lands
  scanvideo — acceptable; keep it compiling by stubbing the video module).

Rationale:
- Two presets make the board split explicit; platform ifdefs are the only
  capability mechanism (no custom feature flags to drift out of sync).
- Host tests turn the bridge code from "trust me" into a fast feedback
  loop; they cost one mock header per subsystem.

---

## Phase 1 — Video Subsystem (core 0)

Goal: fixed 640x480 output, all tile modes + mode 10, serial mirror.

Tasks:
1. ~~Vendor `pico_scanvideo_dpi`~~ deferred to Phase 7 (no hardware to
   validate; the renderer and mirror are implemented and host-tested).
2. ~~Fixed timing: 640x480@60~~ deferred with task 1 (Phase 7).
3. Video state in `system_state_t`:
   ```c
   typedef struct {
       uint8_t  mode;            // 0,1,2,3,10
       uint8_t  *char_map[2];    // double-buffered, swapped at vsync
       uint8_t  *attr_map[2];    // 1 bit invert | 3 bits colour | 4 spare
       uint8_t  tiles[256][8][8];// RAM override set (see rationale)
       uint8_t  *framebuf[2];    // mode 10 only, 320x240
       uint8_t  active;          // which buffer is being written by Lua
       uint32_t palette[256];    // RGB888, mode 10 (and attr colour table)
       volatile uint8_t vsync_version; // incremented by renderer each frame
   } video_state_t;
   ```
4. Scanline renderer (RAM-resident, `__not_in_flash_func`):
   - `render_line(y, out[640*3])`: `row=y/8; sub=y%8`; per column fetch
     `tiles[char_map[row][col]][sub][0..7]`, apply attr (invert, colour),
     emit 3 bytes/pixel (RGB888). Modes 0/1/10 double each pixel and line
     (2x scale); modes 2/3 native.
   - Ping-pong scanline buffers, DMA to HSTX, using scanvideo's scanline
     callback machinery.
5. Mode switching (`ScreenMode`): allocate the needed maps from static
   pools (no malloc), free/return the previous ones, reset active buffer.
   Mode 10 allocates its double framebuffer from a dedicated pool.
6. Lua API module `screen_lua.c`:
   - `ScreenMode(mode)`
   - `ScreenOut(x, y, char)` — also an attribute setter
     (`ScreenAttr(x, y, flags)` or a combined variant)
   - `ScreenDefineTile(index, bytes)` — writes the RAM override set
   - `ScreenPalette(index, r, g, b)` / bulk `ScreenPaletteSet(t)`
   - `ScreenClear([char])`
7. Serial mirror (all boards, always compiled on dev board): core 0 emits
   the text frame protocol from the active char map over the RS232 UART —
   `resolution=`/`foreground=`/`background=` headers on connect and on
   change, one `data=` line per frame (1200 tile values), `tile=` lines
   when Lua redefines tiles. Only for modes 0/1.

Acceptance:
- Host test: renderer produces correct scanline bytes for a known char map
  (golden output), including 2x scaling, invert and colour attributes.
- On the RP2040 dev board: serial mirror shows `os.lua` output as a 40x30
  text frame updating correctly.
- On product board (Phase 7 hardware): 640x480 image on a monitor for all
  tile modes; mode 10 displays framebuffer content.

Rationale:
- Fixed timing means the monitor never resyncs; one code path for sync.
- Double-buffered maps + vsync pointer swap = Lua never blocks the
  renderer and the renderer never sees a half-updated map. The attribute
  map is swapped in the same operation (a small struct of pointers, one
  atomic exchange).
- Tile set lives in **flash** by default (the ASCII font ROM is read-only
  data); `ScreenDefineTile` writes into a RAM override set so per-program
  tile edits are cheap and restorable. Saves 16 KB RAM when unused.
- Scanline rendering keeps RAM free for Lua states; the 640-byte working
  buffers are negligible.

---

## Phase 2 — RS232 Terminal Application (macOS)

Goal: drive the dev board over the serial link from a Mac: render the
tile stream and send keyboard input.

Tasks:
1. **Native macOS app (`../terminal/macos`, sibling folder; SwiftUI):** serial access via IOKit
   (or ORSSerialPort). A virtual display renders the tile stream with the
   font8x8 ROM font (ASCII-aligned, same tiles as the firmware) and the
   fg/bg colours from the stream.
2. **Protocol (text, line-oriented, see AGENTS.md):**
   - device → app: `resolution=40x30`, `foreground=…`, `background=…`
     (on connect and on change; unchanged values are ignored),
     `tile=<index>,<8 bytes>` (custom tiles, on connect and on
     redefine), and one `data=` line per frame with the 1200 tile
     values row-major (decimal or 0x hex, cast to uchar).
   - app → device: `input=<code>` (board synthesises down+up);
     `input=<code>,1` / `input=<code>,0` for explicit press/release
     (modifiers).
3. **Rendering:** repaint on each complete `data=` line; keep the last
   frame while the stream updates; tolerate partial lines mid-frame.
4. **Serial plumbing:** port picker, 115200 8N1, connect/disconnect,
   and an optional raw byte log for debugging the stream protocol.

Acceptance:
- On the dev board: the app renders the tile stream live and typed keys
  produce correct key events visible in Lua `tick()`.
- The same app drives the product board over real RS232 (USB-serial
  adaptor).

Rationale:
- A small native app is the right size for a serial terminal: native
  serial access, low-latency key delivery, and the same font data as the
  firmware. The web IDE is a separate project, so this app stays
  deliberately single-purpose.

---

## Phase 3 — Input Subsystem (core 0)

Goal: keyboard + joysticks + RS232 in, one unified event stream.

Tasks:
1. Unified event struct:
   ```c
   typedef struct {
       uint8_t  type;      // KEY | CONTROL1 | CONTROL2
       uint8_t  key;       // ASCII key code for KEY events
       uint8_t  mods;      // SHIFT | CTRL | C= | RESTORE bits
       uint8_t  pressed;   // 1 = down, 0 = up
       uint8_t  ctrl;      // which controller
       uint8_t  dirs;      // UP|DOWN|LEFT|RIGHT|FIRE bitmask
   } input_event_t;
   ```
2. Keyboard matrix scanner on core 0: timer-driven scan (1 kHz), 16 GPIOs
   (8 rows out, 8 cols in), debounce state machine per key. Map matrix
   positions to ASCII via a lookup table (with shift table for capitals and
   symbols; C= and CTRL combinations). Accept ghosting limitations
   (shift+letter fine, 3-key chords not guaranteed).
3. Joystick reader: poll DSUB9 lines in the same 1 kHz tick, edge-detect
   direction/fire changes into events.
4. RS232 keyboard-in: UART RX on core 0 (IRQ or polled), parses
   `input=` lines → KEY events. A bare code synthesises down+up on the
   board; `,1` / `,0` suffixes give explicit press/release (modifiers).
5. SPSC event queue (ring buffer in `system_state_t`): core 0 pushes,
   core 1 drains between ticks. Drop-oldest policy on overflow.

Acceptance:
- Host test: scanner debounce logic (simulated GPIO pattern) produces the
  correct key events; queue never corrupts under producer floods.
- On dev board: typing in a terminal app produces correct ASCII events
  visible in Lua `tick()`.

Rationale:
- One event schema keeps the Lua side board-agnostic: the C64 matrix and
  the serial port feed the same queue. Debounce and decoding are core 0's
  job by design.
- 1 kHz scan is far beyond human input rates and keeps debounce trivial
  (N-samples-of-M window); timer IRQ is core 0's anyway.

---

## Phase 4 — Dual-Core Runtime and SD RPC

Goal: core 1 scheduler + strict core 0 I/O ownership.

Tasks:
1. Boot: core 0 inits clocks, stdio, SD, video, input; then
   `multicore_launch_core1()`. Core 1 creates the Lua states and enters
   the scheduler loop. IRQs (UART, SPI, timers, HSTX/DMA) stay on core 0.
2. RPC transport: two fixed queues (request, response) + a semaphore for
   core 1 to block on completion. Small fixed request/response buffers
   (paths ≤ 128 bytes, data chunks ≤ 4 KB staged through a shared buffer).
3. Move FatFs fully behind the RPC:
   - Core 0 runs the FatFs calls (`f_open`/`f_read`/...) and owns all
     `FIL` handles.
   - `fs_lua.c` (renamed from `fatfs_lua.c`) sends RPCs; Lua file objects
     hold a handle id, not a `FIL*`. Add `fs.readall(path)` and
     `fs.writeall(path, data)`.
   - Script loading (`dofile`/`loadfile`/`require`) also goes through the
     RPC (read file via core 0, compile on core 1).
4. Watchdog: core 0 feeds the hardware watchdog only if core 1's heartbeat
   counter is advancing (stuck VM = system reset).
5. Core 1 scheduler loop:
   ```
   for (;;) {
       heartbeat++;
       drain input queue -> current program's event state
       now = time_us_64();
       if (timer due) run due timer callbacks
       else tick();
   }
   ```

Acceptance:
- Host test: RPC protocol round-trip under a mock core 0; fs module tests
  pass over the RPC path instead of direct FatFs calls.
- On dev board: `os.lua` runs with SD access via RPC; pulling the SD card
  produces clean Lua errors, not crashes.

Rationale:
- Strict single-owner I/O kills every reentrancy/locking question in FatFs
  and SPI at the root. Core 1 blocking on a semaphore costs nothing for
  this workload (file ops are user-paced).
- Heartbeat-gated watchdog catches both core-0 and core-1 wedges with one
  mechanism.

---

## Phase 5 — Process Model

Goal: stack of Lua programs with setup/tick/finish, timers, save/restore.

Tasks:
1. Process struct:
   ```c
   typedef struct program_t {
       uint32_t pid;
       lua_State *L;
       int  tick_ref, setup_ref, finish_ref;  // registry refs
       video_snapshot_t *snapshot;            // saved video state
       timer_t *timers;                       // deadline list
       input_event_t *events;                 // ring buffer for tick()
       struct program_t *next;
   } program_t;
   ```
   A fixed pool of `program_t` (e.g. 4) caps stack depth and memory.
2. Memory policy: per-program Lua heap budget via a custom allocator
   (`lua_newstate` with a cap, e.g. 96 KB heap + 16 KB stack); video
   snapshots come from a fixed pool sized for the worst case (mode 2/3:
   9.6 KB maps + up to 16 KB tile overrides + palette).
3. Video snapshot/restore: on pause, copy current maps/tiles/palette into
   the snapshot and set a fresh video state for the new program; on
   restore, copy back and swap the active buffers. (Copy is ≤ 30 KB,
   one-off, and avoids the aliasing bugs of shared buffers.)
4. Program API in C: `program_launch(path)`, `program_exit()`,
   `program_pause()`. Each `tick()` runs under `lua_pcall`; errors print
   via stdio and terminate the program (shell resumes).
5. Timers: per-program deadline list (array scan is fine), 1 ms resolution,
   `TimerCreate(fn, interval_ms [, oneshot])`, `TimerStop(id)`. Deadlines
   are absolute `time_us_64`; on resume, shift all deadlines by the pause
   duration (no catch-up bursts).
6. Sys module (`sys_lua.c`): `TimeNow()` (ms), `ExitProgram()`,
   `Pid()`, maybe `Launch(path)`.
7. Shell: `os.lua` becomes the CLI — `dir`, `run <prog>`, `quit`. The
   shell is just another program (pid 0).

Acceptance:
- Host test: launch A → A launches B → B exits → A's tick resumes with its
  video state restored; timers fire correctly across pause/resume; a
  throwing tick terminates the program and resumes the parent.
- On dev board: shell runs over serial, runs a demo program, returns to
  the shell with screen restored.

Rationale:
- Copy-on-switch snapshots are simple and memory-bounded; aliasing/shared
  buffers are the classic source of subtle video bugs and aren't worth it
  for ≤ 30 KB.
- Fixed pools (programs, snapshots) mean the OS has no fragmentation
  story at all — allocation failure = "can't launch", a clean Lua error.
- pcall-per-tick isolates faults: a bad program can never take down the
  shell or the OS.

---

## Phase 6 — Editor

Goal: the first real application, exercising every subsystem.

Tasks:
1. `fs.readall` / `fs.writeall` over RPC (Phase 4 already adds them).
2. Editor program (`editor/` folder on SD): load file into RAM (gap
   buffer), render via tile modes, cursor blink via a 500 ms timer,
   keyboard events drive movement/insert/delete, Save writes back through
   RPC.
3. Key handling details: C64 cursor keys (shifted layout) mapped to
   movement; shift+letter capitals; INST/DEL insert/delete semantics.
4. Polish: status line (filename, row/col), dirty flag, save confirmation.

Acceptance:
- On dev board (serial): full edit/save/load cycle of a Lua file,
  verified by reloading it in the shell.

Rationale:
- In-RAM editing makes insert O(1) amortised (gap buffer) and avoids
  wear-leveling concerns on the card; whole-file save is one RPC.

---

## Phase 7 — Product Board Bring-Up (RP2354B)

Goal: HDMI + full input on real hardware.

Tasks:
1. Board header for RP2354B (flash size, pin map, platform rp2350).
2. Validate HSTX/scanvideo timing on a real monitor.
3. Validate SD on SPI1 GP8–11 and both SPI busses coexisting.
4. Validate matrix + joystick wiring, debounce tuning on real keys.
5. Burn-in: soak test (editor + game loop) with watchdog armed.

---

## Phase 8 — Audio Subsystem

Goal: Lua-authored tones and looping multi-channel scores over HDMI audio
(product board; the RP2040 dev board has no audio output path).

Status: the engine, Lua API, per-program state and WAV loading are
implemented and host-tested (`audio.c`, `sound_lua.c`,
`spicomputer_audio_tests`). The HDMI data-island feed lands with the
Phase 7 hardware bring-up (task 1), which is the only hardware-gated part.

Tasks:
1. Settle the single HSTX owner (Phase 7 decision): `pico_hdmi` (HSTX HDMI
   including audio data islands, Unlicense) vs `pico_scanvideo_dpi` (video
   only) plus ported data-island code. Vendor the winner and keep it behind
   `video_hw.c` / `audio_hw.c` so only one file each touches it. *(pending:
   hardware)*
2. Core 0 realtime engine: 8-channel integer mixer at 44.1 kHz (waveform +
   envelope voices), score cursor with looping, one-shot effect voices,
   master volume; feeds the HDMI audio packet queue (silence + starvation
   counter on underrun). **Implemented** as the platform-neutral producer
   (`audio_mix`); the HDMI packet feed lands with task 1.
3. Lua API (`sound_lua.c`): **implemented** (see `lua.md`). `*Define`
   compiles Lua tables into flat per-program buffers (outside the 64 KB Lua
   heap), published to core 0 by pointer swap.
4. Per-program audio state (like video): **implemented** - publish on
   program switch, silence paused programs, resume score position, free on
   exit.
5. WAV sample loading: **implemented** - `SoundLoad(path)` streams PCM
   (8/16-bit, mono/stereo) via the fs RPC into a 64 KB per-program pool;
   IMA ADPCM remains a possible later size optimisation.
6. Host tests: **implemented** - oscillator/envelope/mixer behaviour, score
   scheduling and loop wrap, pause/resume across a program launch, WAV
   parsing over the mock SD, and the full Lua API.

Acceptance:
- ~~Host tests pass.~~ (done)
- On the product board: a defined score plays and loops over HDMI, one-shot
  effects mix over it, and editor/game use causes no dropouts.

Rationale:
- Core 0 owns every sample: timing is sample-accurate and cannot be
  perturbed by Lua ticks, GC or SD RPC stalls on core 1.
- Scores are authored as Lua tables (readable, diffable) but compiled to
  flat buffers, so the realtime path never enters Lua.
- HDMI data-island audio keeps the pin budget intact; I2S/PWM audio stays a
  fallback only if HSTX data islands prove unreliable on real sinks.

---

## Memory Budget (RP2354B, 520 KB)

| Consumer | Size |
|---|---|
| Core 0: scanline buffers, DMA, event/RPC queues | ~12 KB |
| Mode 10 double framebuffers (active only in mode 10) | 153.6 KB |
| Tile override RAM set | 16 KB |
| Audio per program: instruments + scores + 1024-event pool, heap-allocated like video | ~15 KB |
| WAV sample pool per program (malloc'd on first SoundLoad) | up to 64 KB |
| Char+attr maps (mode 2/3 worst case, double-buffered) | 19.2 KB |
| Video state per program (heap-allocated on launch, 4 × ~28 KB on demand) | ~112 KB worst case |
| Lua states: 4 programs × (64 KB heap cap + VM) | ~280 KB worst case |
| Font ROM (flash) | 16 KB (flash) |

Mode 10 and deep program stacks are mutually constrained in practice:
a pixel-mode game holds no paused programs, and the shell/editor stack
lives comfortably in tile modes. Documented as a policy: **mode 10 is
single-program; launching from a mode 10 program is rejected with a Lua
error.** (Revisit if a real need appears.)

## Flash Budget (2 MB)

Firmware + Lua + FatFs + scanvideo ≈ 600 KB, leaving > 1 MB for the font
ROM, future embedded assets, and (optionally) littlefs config storage.

## Risk Register

| Risk | Mitigation |
|---|---|
| scanvideo on RP2350 is immature/changes API | Vendor a pinned revision; wrap behind `video.c` so only one file touches it |
| C64 matrix ghosting surprises users | Document; offer serial keyboard as the reliable path |
| ~3 fps full-frame serial mirror too slow for editor UX | Editor redraws dirty cells only; or add a changed-cells delta record to the text protocol later (backwards-compatible new record type) |
| Lua heap fragmentation across long sessions | Bounded per-program allocators + program exit frees everything |
| HSTX + SPI1 coexistence bugs on real silicon | Phase 7 burn-in; SD access and video run simultaneously from day one in tests |
| Terminal app drifts from firmware behaviour | Parser + font are canonical in the OS repo and vendored into the app; `sync-protocol.sh` refreshes the copies, golden stream vectors live in `tests/host` |
| macOS serial access friction (driver quirks, sandbox) | ORSSerialPort/IOKit is the well-trodden path; USB-serial adaptors work without custom drivers |

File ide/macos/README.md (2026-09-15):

# SPIComputer IDE (macOS)

A SwiftUI development environment for SPIComputer OS programs. Projects
are folders of components that build into matching `.lua` source and `.prg`
compiled outputs; **Run** writes both files into a simulator SD card and
launches the compiled program in the desktop simulator.

Lives next to `system/` and `simulator/` (it is not part of the system
itself).

## Build & run

```bash
cd ide/macos
swift run SPIIDE        # development launch
swift test              # core build/emission logic tests
swift run spibuild <project-folder>   # headless Build (see below)
./scripts/build-app.sh  # release .app with bundled simulator
```

The package is self-contained: `Sources/SPIIDECore/Resources/` vendors the
OS simulator (`simulator/spicomputer_sim` with its SDL2 library beside it,
loaded via `@loader_path`) and a minimal card image (`sdcard/core/` with
`boot.prg` and `os.prg`). SwiftPM copies both into the SPIIDECore resource
bundle, so `swift run`, `swift test`, `spibuild` and the packaged app all
find the same simulator (`BundledResources`), and Run can boot an
application under the bundled OS with no SD card image configured. The
locator still honours `SPICOMPUTER_SIMULATOR`, the path in **Settings**, and
a `simulator/build/spicomputer_sim` in an enclosing OS workspace, in that
order of preference after the explicit path.

`./scripts/update-vendor.sh [os-workspace]` refreshes the vendored files
from an OS checkout: it builds the simulator in Release, rewrites its SDL
reference, ad-hoc signs it, and rebuilds `boot` and `os` with `spibuild`.
Run it whenever the OS changes and commit the results.

`./scripts/build-app.sh` builds a release `SPIComputer IDE.app` in `dist/`
from this package alone: the executable, the two resource bundles (icon;
frameworks, simulator, card image) and an Info.plist, ad-hoc signed.

`spibuild` is the headless counterpart of the IDE's Build button: it
loads `project.spiproj`, compiles the components and writes the program
to the project's output directory, so projects can be built from a
terminal or CI as well as from the IDE:

```bash
swift run spibuild /path/to/My-Project
```

The Dock icon is set at launch from `Sources/SPIIDE/Resources/AppIcon.png`
(`swift run` produces a bare executable, so there is no app bundle to
carry an icon).

## Recent projects

The welcome screen (shown while no project is open) lists the ten most
recently opened projects with their path and when they were last opened;
click one to open it, right-click to reveal it in the Finder or remove
it. The same list is under File ▸ Open Recent. The list lives in
UserDefaults (`recentProjects`) and drops projects whose folder has
disappeared.

## Projects

The first item in the project navigator is Project Settings. It controls the
name, version, description, **kind**, video/audio requirements, install
folder, frameworks and optional icon.

### Kinds

| Kind | Products in `build/` | Installs to | Run from the IDE |
|---|---|---|---|
| Raw program | `name.lua`, `name.prg` | `data/` (or the manifest's `install_directory`: `core` for boot and the shell) | boots the `.prg` directly, no OS |
| Application | + `name.app/` (`app.prg`, `app.json`, `resources/`) | `apps/` | installs into a temp card with the OS from your SD card image and boots the OS; run it from the shell |
| Utility | + `name.util/` | `utils/` | same; it is a shell command with no screen of its own that returns a table (`UtilityResult(ok, table)`) |
| Game | + `name.game/` | `games/` | boots the `.game` directly; on the OS it replaces the shell and the device restarts when it exits |

Every product goes into the project's own `build/` folder; nothing is
written anywhere else. **Install** (⌘I) copies the product into the SD
card image set in Settings (a folder laid out like the card: `core/`,
`apps/`, `utils/`, `games/`, `data/`), which is what you copy to a real
card. `software/install.sh` in the workspace builds and installs every
card project into `software/sdcard/`.

A project is a folder with a manifest and component files:

```
My Program/
  project.spiproj          manifest: name, kind, ordered component list
  components/
    00-header.lua          snippet component (build-only comments/constants)
    main.lua               Lua component (setup/tick/finish)
    sprites.json           tiles & palette asset
    music.json             sounds & score asset
  build/
    My-Program.lua         generated source program (do not edit)
    My-Program.prg         generated Lua bytecode (do not edit)
    My-Program.app/        bundle (.app / .util / .game by kind)
      app.prg              bundle entry point
      app.json             metadata (name, version, description, type, ...)
      resources/           bundled resources
    run/sdcard/            the card the simulator boots for Run
```

Manifests written by earlier versions (`output_kind`, `output_directory`,
`interactive`) are read and migrated to a kind on load.

All components are concatenated **in sidebar order** (drag to reorder)
into one Lua program with a generated header.
Components are plain files on disk — edit them with any tool.

### Component kinds

| Kind | File | Emitted as |
|---|---|---|
| Lua Code | `.lua` | verbatim |
| Snippet | `.lua` | verbatim (for build-only material) |
| Tiles & Palette | `.json` | `ScreenPaletteSet` / `ScreenDefineTile` calls inside an asset function |
| Sounds & Music | `.json` | `SoundDefine` / `MusicDefine` calls inside an asset function |

Asset components register themselves in `__spi_assets`; the generated
tail defines `ApplyAssets()`, which the starter `setup()` calls so the
assets are applied while the program's video/audio state is current.

### New project template

`New Project…` always creates four components:

- **header** (snippet) — build-only documentation/constants.
- **main** (Lua) — empty `setup()`/`finish()` with comments above them
  listing the screen modes and text output (`ScreenOut`/`ScreenClear`).
- **input** (Lua) — empty `on_keypress(key, shift, ctrl, cbm, restore)`
  and `on_control(index, up, down, left, right, fire)` with comments
  describing what each parameter receives (index 0/1 for joystick 1/2).
  Both are optional; delete the one you don't need, or poll `InputPoll()`.
- **tick** (Lua) — the empty `tick()` loop with comments on where it sits
  in the lifecycle.

Components build top-to-bottom into one Lua chunk, so the locals declared
in `main` are visible to `input` and `tick`.

## Frameworks (SDKs)

`Sources/SPIIDECore/Resources/sdk/*.lua` are read-only frameworks a project
can select in Project Settings. New projects, and projects whose manifest
predates frameworks (no `sdks` key), select them all; untick to opt out.
They are: `screen`
(`Screen.*`: text, windows, fills, block moves, lines, shades, progress
bars, mode-10 pixel lines and rectangles), `overlay` (`Overlay.*`: the
same on the overlay, plus dialogs), `text` (`Text.*`: alignment,
padding, wrapping, number formatting), `timer` (`Timer.*`: timer objects
with an id that can be cancelled, paused, resumed and restarted; `t:Pause()`
and `Timer.Pause(t)` are the same call), `sound` (`Sound.*`, `Music.*`) and
`input` (`Input.Keyboard.*`, `Input.Joystick.*`). They are plain Lua over
the OS API, injected into the built program after the `__spi_*` flags
and before the components, so their namespaces exist when the program's
chunk body runs.

Only what the program uses is emitted. The builder reads each framework
as a preamble (everything above the first column-0 `function`, always
kept) plus `function Name.Sub(...)` … `end` blocks (both at column 0),
keeps the blocks whose names the program's Lua/snippet components mention
(strings and comments masked out), then the blocks those mention, and so
on; `local function helper` blocks come along when a kept block uses
them. A framework nothing uses emits only a banner. The `---` line above
a block (`--- Screen.OutText(x, y, text [, attr])`) is its signature for
completion and parameter help; the `--` lines after it describe it. Keep
that format when editing a framework, and add a test in
`SDKLibraryTests` for anything new the parser must understand.

`software/demo` uses all four frameworks and writes a self-test file;
running it headless in the simulator with `--type 'k'` is the frameworks'
integration test.

## Help panel

Right-click any name in the editor (`Screen.OutText`, `fs.open`,
`f:read`, `string.format`, `for`) and choose **Help for …**: a panel on
the right shows the signature, summary, parameters, return value, notes,
an example and see-also links, and stays open while you type. The book
button in the toolbar, or View ▸ Show Help Panel (⌘⇧H), toggles it; its
search field looks up any name, and with no topic it lists every group.

The content lives in `Sources/SPIIDECore/Resources/help/*.json`
(`lua.json`, `os.json`, `sdk.json`; schema in that folder's README).
**It is the documentation of record**: adding or changing an API call, a
framework function or a Lua facility means updating the entry there in
the same change. `HelpLibraryTests` fails when a completion-table name or
a framework function has no entry, when a framework entry's signature
drifts from the `---` line in the framework file, or when a see-also link
points nowhere.

## Compile checking and editing

Background checks never move you: the error line is marked in the gutter
and the banner names it, and the caret and viewport stay where you are
typing (an incomplete line is often reported far from where it was
typed). "Go to Line" on a banner is the explicit jump. A runtime error
from the running program shows its banner above whichever component you
are editing, naming the component it belongs to, with "Show" to switch
to it; it no longer switches components by itself.

- The editor shows **line numbers** in a gutter per component file.
- After a short debounce, the IDE builds the project in memory and
  compiles it with the OS's own Lua build (`spicomputer_sim --check`), so
  what you see is exactly what the OS will load.
- Two seconds after you stop typing, the file being edited is also
  syntax-checked on its own, so errors show up without waiting for a
  build. The project navigator marks every component with a known
  syntax error (red icon and message) until the program compiles.
- Compile errors are mapped back through the build's line map: Lua's
  "line 41" in the generated file is shown as e.g. `main:13`, the error
  line is highlighted in the editor and its number turns red in the
  gutter, and the message appears in a banner and in the Build & Run log.
- Open Lua and snippet components are polled for external changes. Agent or
  editor updates are reloaded automatically when the IDE has no unsaved edits;
  conflicting changes are kept in the editor and reported in the console.
  When Lua only reports `<eof>` (a missing `end`), the IDE uses Lua's
  "at line N" context or its own block-structure check to point at the
  unclosed function/if/for/while/repeat instead.
- If the simulator binary cannot be found (checks run through its `--check`
  mode), an orange banner says so; the IDE looks next to itself, in the
  current directory, and along the compiled-in source path (so Xcode
  builds work too), and Settings can override it.
- **Run** refuses to start while a compile error is outstanding.
- **Autocompletion** covers Lua keywords and standard library plus the
  SPIComputer globals (`Screen*`, `Sound*`, `Music*`, `Timer*`, `Input*`,
  `fs.*`, `TimeNow`, `Launch`, `ApplyAssets`, ...). Functions defined in
  the file being edited, and in the project's other components, join the
  list, and known functions show their expected parameters beside the
  name. The list appears shortly after you type (two or more characters),
  or on demand with Ctrl-Esc / **Edit ▸ Complete** (⌃Space), which also
  steps through the list once open. Up/Down choose, Tab or Return insert,
  Esc dismisses. Backspace only dismisses and always deletes, and
  deleting never reopens the list; the inline macOS "automatic text
  completion" is disabled so this list is what appears.
- **Parameter help**: while the caret is inside a call's argument list
  (`ScreenOut(1, `), a strip under the caret shows the signature with
  the current parameter emphasised, following the caret until the call
  is closed. It covers the SPIComputer API, the Lua standard library,
  the `fs` file methods, and functions defined in the project.
- **Auto-indent**: Return keeps the current indentation and adds a level
  after block openers (`then`, `do`, `function`, `else`, `repeat`, `{`,
  `(`, function headers). After an opener that needs a closer
  (`function`, `if`/`for`/`while`, `{`, `(`), Return also puts the
  matching `end`/`}`/`)` on its own line at the opener's indentation and
  leaves the caret on the body line above it. Typing `end`, `until`,
  `else`, `elseif`, `}` or `)` at the start of a line removes one level.
- **Syntax highlighting** colours comments, strings, numbers, keywords
  and known functions (temporary attributes, so undo and the text buffer
  are untouched).

## Run in the simulator

**Run** (⌘R) builds, prepares `build/run/sdcard/` and starts
`simulator/build/spicomputer_sim --sdcard … --boot <program>`. A raw
program or a game is booted directly with nothing underneath. An
application or utility needs the OS: `core/` is copied from the SD card
image set in Settings, the bundle is installed into `apps/` or `utils/`,
and the simulator boots `core/boot`; run the program from the shell by
name. **Stop** terminates the simulator. The Build & Run console shows
the build result and the simulator's output.

The `.prg` file is Lua 5.5 binary bytecode generated by the simulator's
`--compile` mode, using the same Lua build that loads programs on the OS.

- Hover documentation (a tooltip on the call under the mouse; parameter
  help covers the signature already).

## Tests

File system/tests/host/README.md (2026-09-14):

# Host Tests

Run the OS's Lua↔SD bridge on the developer machine using a mock FatFs/SD
layer. No hardware needed.

```bash
cmake -S tests/host -B build-host
cmake --build build-host
./build-host/spicomputer_host_tests
./build-host/spicomputer_input_tests
./build-host/spicomputer_program_tests
./build-host/spicomputer_render_tests
./build-host/spicomputer_editor_tests
```

The main test binary compiles the real Lua 5.5 core (from `../../lua`), the
real RPC transport (`rpc.c`) and the real `fs_lua.c`/`fs_core0.c` stack,
substituting mock `ff.h` / `f_util.h` / `hw_config.h` headers for the
FatFs/SD hardware layer. The RPC wait hook runs the core 0 service inline,
exactly as the firmware main loop would.

Covered:
1. Booting a card program (fixture) through the process model
2. SD-backed `dofile` from within Lua
3. SD-backed `loadfile` semantics (function / nil+err)
4. `require()` via the SD searcher
5. The full `fs` module API (open/read/write/seek/tell/size/flush/close,
   ls/stat/exists/free/ready)
6. Error handling for missing files
7. `fs.readall` / `fs.writeall` over the RPC path
8. Ejected SD card: clean Lua errors, no crashes
9. Explicit RPC round-trip against the mock core 0 service
10. A typed command line (fixture): input events, case-insensitive
    program lookup with `fs.find`, `Execute` with arguments, QUIT

`spicomputer_input_tests` exercises the input engine (`input.c`) with
simulated GPIO patterns: SPSC queue round-trip and producer-flood drop-oldest
behaviour, matrix debounce, shift handling, joystick edge detection, and
RESTORE handling.

`spicomputer_program_tests` exercises the process model: launch/resume
with video state restore, tick-crash termination, timers (incl. pause
deadline shifting), input deposit, failed launches.

`spicomputer_render_tests` exercises the video pieces: the scanline
renderer (golden output, 2x scaling, attribute colours, base + overlay
composition, custom tiles, mode 10), the change queue, and the screen /
overlay Lua modules.

`spicomputer_audio_tests` exercises the Phase 8 audio pieces: note
parsing, oscillators, envelopes, pan/master volume, score scheduling
and loop wrap, one-shot behaviour, PCM sample playback, WAV loading
over the mock SD, the full sound/music Lua API, and audio state
across a program launch/resume.

`spicomputer_editor_tests` boots an `editor.lua` supplied on the
command line against the mock SD card and simulates typing through the
normal event path: initial render + status line, insert, ANSI cursor
sequence, backspace, dirty save confirmation, and the file written
back to the mock SD. The editor lives in its own project outside this
repo, so the harness skips when no path is given:

```
./build-host/spicomputer_editor_tests /path/to/editor.lua
```

As more subsystems gain mock headers, add their host tests here.

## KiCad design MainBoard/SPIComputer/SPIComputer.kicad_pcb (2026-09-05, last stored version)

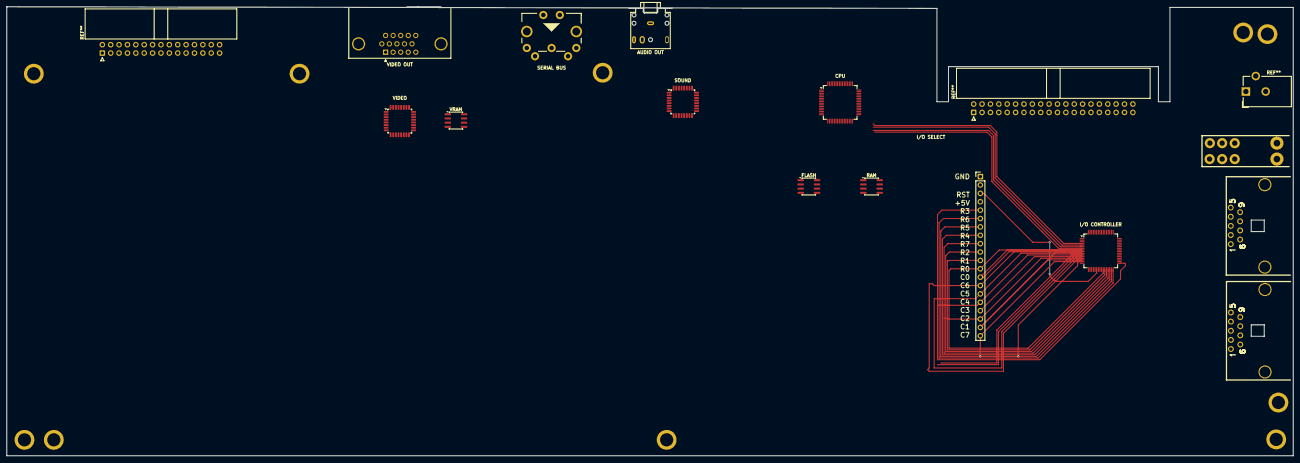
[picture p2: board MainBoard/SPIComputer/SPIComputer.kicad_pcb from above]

Board: 2 copper layers, 390.0 x 136.1 mm, 14 parts (0 on the bottom side), 2 nets.

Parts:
AUDIO OUT: Jack_3.5mm; Jack_3.5mm_CUI_SJ1-3524N_Horizontal
CN8, CN9: JOYPORT_DB9
CPU: AVR128DB64-I-PT
FLASH: SOIC-8_3.9x4.9mm_P1.27mm
HOLE4: (no value)
I/O CONTROLLER: AVR128DB64-I-PT
RAM: SOIC-8_3.9x4.9mm_P1.27mm
SERIAL BUS: DIN5_MIDI
SOUND: AVR128DA32-I-PT
SW1: POWER_SWITCH
VIDEO: AVR128DA32-I-PT
VIDEO OUT: DSUB-15-HD_Socket_Horizontal_P2.29x2.54mm_EdgePin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; DSUB-15-HD_Socket_Horizontal_P2.29x2.54mm_EdgePinOffset8.35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
VRAM: SOIC-8_3.9x4.9mm_P1.27mm

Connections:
+5V: CN8.7, CN9.7, SW1.4
GND: CN8.8, CN9.8, HOLE4.1, SW1.pe (SHIELD)

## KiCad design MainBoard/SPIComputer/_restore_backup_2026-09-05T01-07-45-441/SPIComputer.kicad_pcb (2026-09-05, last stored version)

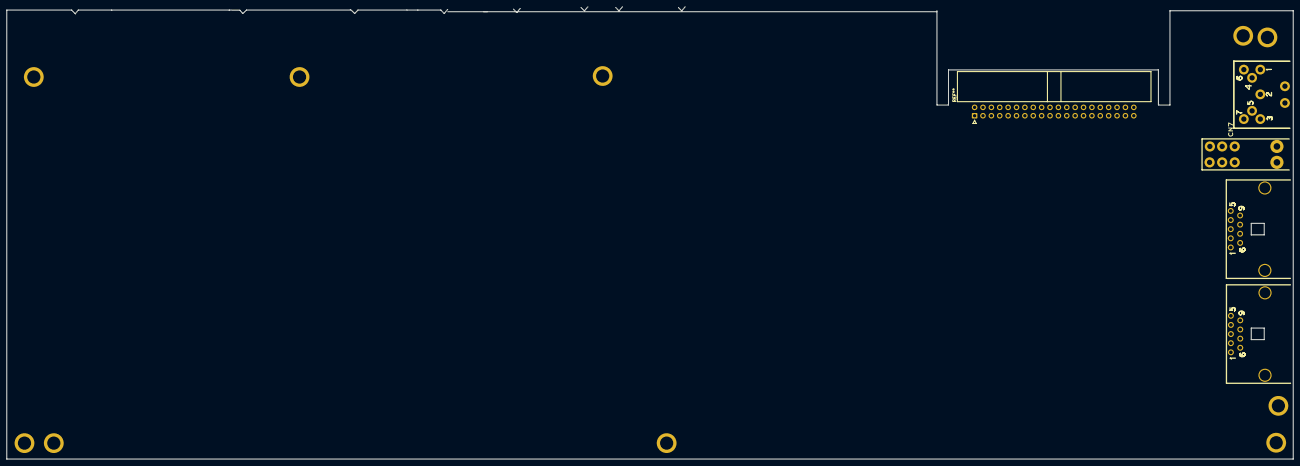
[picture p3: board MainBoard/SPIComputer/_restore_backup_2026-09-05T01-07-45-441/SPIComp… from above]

Board: 2 copper layers, 390.0 x 137.1 mm, 5 parts (0 on the bottom side), 4 nets, no tracks yet.

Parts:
CN7: POWER_CON_D7_250407
CN8, CN9: JOYPORT_DB9
HOLE4: (no value)
SW1: POWER_SWITCH

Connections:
+5V: CN8.7, CN9.7, SW1.4
/+5V': CN7.4, CN7.5
/GND': CN7.1, CN7.2, CN7.3
GND: CN7.pe (shield), CN8.8, CN9.8, HOLE4.1, SW1.pe (SHIELD)

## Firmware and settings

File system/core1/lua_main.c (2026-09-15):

/* core1/lua_main.c
 *
 * Core 1: the OS core. Everything except the video scanout runs here:
 * stdio, the SD card and FatFs (so filesystem calls are direct, with no
 * RPC or locks against the Lua thread), input scanning (1 kHz timer IRQ),
 * the watchdog and the Lua scheduler.
 *
 * Core 0 runs the HSTX scanout only. The single object shared between the
 * cores is g_system_state.video_frame_count, which core 0 writes at each
 * vertical blank; this core reads it for WaitVSync, for the video-state
 * retire queue and for the watchdog gate below.
 *
 * Core affinity rules (see also core0/main.c):
 *   - stdio is initialised here and must only be used from this core;
 *   - the alarm pool (timers, sleep_*) is claimed by whichever core first
 *     uses it, so this core takes it for the 1 kHz input tick and core 0
 *     avoids sleep_ms()/timers entirely;
 *   - each IRQ belongs to the core that enables it: the SD SPI's
 *     DMA_IRQ_0 and the timer IRQ are enabled here, the video IRQs on
 *     core 0.
 */

#include <stdarg.h>
#include <stdio.h>
#include <string.h>
#include "pico/stdlib.h"
#include "hardware/clocks.h"
#include "hardware/watchdog.h"
#if defined(PICO_RP2350)
#include "hardware/structs/powman.h"
#endif

#include "board_config.h"
#include "boot_signal.h"
#include "fs_core0.h"
#include "input_hw.h"
#include "program.h"
#include "rpc.h"
#include "scanout.h"
#include "system_state.h"
#include "video_hw.h"

// Boot program loaded from the SD card root at startup (starts the
// shell, os.lua, in the foreground).
#define BOOT_SCRIPT "core/boot.lua"

/* A frozen display is as fatal as a frozen VM: if the frame counter has
 * not moved for this long, stop feeding the watchdog. */
#define VIDEO_STALL_LIMIT_US 250000

/* Bring-up status period (SPICOMPUTER_LOG_PERIOD_MS, default 1000): a
 * video status line per period goes to USB stdio and to SPILOG_FILE on
 * the card (see sd_log below). */
#ifndef SPICOMPUTER_LOG_PERIOD_MS
#define SPICOMPUTER_LOG_PERIOD_MS 1000
#endif
#if SPICOMPUTER_LOG_PERIOD_MS < 1
#undef SPICOMPUTER_LOG_PERIOD_MS
#define SPICOMPUTER_LOG_PERIOD_MS 1
#endif
#define LOG_PERIOD_US ((uint64_t)SPICOMPUTER_LOG_PERIOD_MS * 1000u)

/* ... but give the display time to come up before enforcing that. */
#define VIDEO_BOOT_GRACE_US 5000000

/* Filesystem calls run inline on this core, so a long `fs.readall` /
 * `fs.writeall` (many 4 KB operations inside one Lua call) can keep the
 * scheduler busy for longer than the watchdog period. A completed
 * filesystem operation is evidence of progress, so refresh the watchdog
 * around each one: a hung SD transfer still stops the feeds (the update
 * below happens before and after, never during), while a program that
 * streams files legitimately no longer trips the reset. */
static void fs_service(const rpc_request_t *req, rpc_response_t *resp) {
    watchdog_update();
    fs_core0_execute(req, resp);
    watchdog_update();
}

/* ------------------------------------------------------------------ */
/* Bring-up log on the SD card                                        */
/*                                                                    */
/* The bench has no working USB console, so the boot report and the  */
/* per-period video status also go to SPILOG_FILE in the card root.   */
/* Lines collect in RAM (lines logged before the mount wait there)    */
/* and sd_log_flush() appends them with one open/append/close, so     */
/* everything flushed is on the card before a reset can lose it.      */
/* Each boot starts with a "=== boot" line.                           */
/* ------------------------------------------------------------------ */

#define SPILOG_FILE "spilog.txt"

static char s_log_buf[2048];
static size_t s_log_len;

static void sd_log(const char *format, ...) {
    char line[200];
    va_list args;
    va_start(args, format);
    int n = vsnprintf(line, sizeof(line) - 1, format, args);
    va_end(args);
    if (n < 0) {
        return;
    }
    if ((size_t)n > sizeof(line) - 2) {
        n = (int)(sizeof(line) - 2); /* truncated */
    }
    line[n++] = '\n';
    line[n] = '\0';
    fputs(line, stdout);
    if (s_log_len + (size_t)n <= sizeof(s_log_buf)) {
        memcpy(s_log_buf + s_log_len, line, (size_t)n);
        s_log_len += (size_t)n;
    }
}

static void sd_log_flush(void) {
    if (s_log_len == 0 || !fs_core0_mounted()) {
        return; /* no card yet: keep the lines for the next flush */
    }
    fs_core0_append(SPILOG_FILE, s_log_buf, s_log_len);
    s_log_len = 0; /* a failed write is dropped rather than retried */
}

/* Breadcrumbs in the watchdog scratch registers, which survive a
 * watchdog reset (a power-on clears them). Updated as the OS core runs,
 * read back and logged at the next boot, so a reset leaves a record of
 * how long the previous run lasted and what this core was doing when it
 * stopped. Scratch 4-7 belong to the SDK/bootrom. */
#define CRUMB_MAGIC 0x5b10c0deu
#define CRUMB_SCRATCH_MAGIC 0
#define CRUMB_SCRATCH_UPTIME 1
#define CRUMB_SCRATCH_PHASE 2

enum {
    PHASE_BOOT = 1,      /* stdio, card mount, first program load */
    PHASE_SCHEDULER = 2, /* inside program_scheduler_step (Lua) */
    PHASE_LOOP = 3,      /* the loop's own bookkeeping */
    PHASE_LOG = 4,       /* writing spilog.txt */
};

static void crumb_phase(uint32_t phase) {
    watchdog_hw->scratch[CRUMB_SCRATCH_PHASE] = phase;
}

static const char *phase_name(uint32_t phase) {
    switch (phase) {
        case PHASE_BOOT: return "boot";
        case PHASE_SCHEDULER: return "Lua scheduler step";
        case PHASE_LOOP: return "scheduler loop";
        case PHASE_LOG: return "writing the SD log";
        default: return "unknown";
    }
}

static void log_reset_reason(bool was_watchdog) {
    sd_log("=== boot (SPIComputerOS, %s %s)", __DATE__, __TIME__);
#if defined(PICO_RP2350)
    uint32_t r = powman_hw->chip_reset;
    sd_log("reset: chip_reset=0x%08lx%s%s%s%s%s%s%s%s", (unsigned long)r,
           (r & POWMAN_CHIP_RESET_HAD_POR_BITS) ? " power-on" : "",
           (r & POWMAN_CHIP_RESET_HAD_BOR_BITS) ? " BROWN-OUT" : "",
           (r & POWMAN_CHIP_RESET_HAD_RUN_LOW_BITS) ? " RUN-pin" : "",
           (r & POWMAN_CHIP_RESET_HAD_GLITCH_DETECT_BITS) ? " GLITCH" : "",
           (r & (POWMAN_CHIP_RESET_HAD_WATCHDOG_RESET_PSM_BITS |
                 POWMAN_CHIP_RESET_HAD_WATCHDOG_RESET_SWCORE_BITS |
                 POWMAN_CHIP_RESET_HAD_WATCHDOG_RESET_POWMAN_BITS |
                 POWMAN_CHIP_RESET_HAD_WATCHDOG_RESET_POWMAN_ASYNC_BITS))
               ? " watchdog"
               : "",
           (r & POWMAN_CHIP_RESET_HAD_RESCUE_BITS) ? " rescue" : "",
           (r & POWMAN_CHIP_RESET_HAD_DP_RESET_REQ_BITS) ? " debugger" : "",
           (r & POWMAN_CHIP_RESET_HAD_HZD_SYS_RESET_REQ_BITS) ? " sys-reset-req"
                                                               : "");
#endif
    if (was_watchdog) {
        sd_log("reset: rebooted by the watchdog timer");
    }
    if (watchdog_hw->scratch[CRUMB_SCRATCH_MAGIC] == CRUMB_MAGIC) {
        uint32_t phase = watchdog_hw->scratch[CRUMB_SCRATCH_PHASE];
        sd_log("reset: previous run lasted %lus; it stopped during: %s",
               (unsigned long)watchdog_hw->scratch[CRUMB_SCRATCH_UPTIME],
               phase_name(phase));
    } else {
        sd_log("reset: no record of a previous run (power-on or RUN pin)");
    }
    watchdog_hw->scratch[CRUMB_SCRATCH_MAGIC] = CRUMB_MAGIC;
    watchdog_hw->scratch[CRUMB_SCRATCH_UPTIME] = 0;
    crumb_phase(PHASE_BOOT);
}

static void print_boot_info(void) {
    uint32_t sys = clock_get_hz(clk_sys);
    sd_log("clocks: sys %lu Hz, peri %lu Hz, usb %lu Hz, refresh %u Hz",
           (unsigned long)sys, (unsigned long)clock_get_hz(clk_peri),
           (unsigned long)clock_get_hz(clk_usb),
           (unsigned)SPICOMPUTER_REFRESH_HZ);
#if defined(PICO_RP2350)
    if (sys / 1000 != SPICOMPUTER_SYS_CLOCK_KHZ) {
        sd_log("overclock: %u kHz is not exactly achievable; using %u kHz",
               (unsigned)SPICOMPUTER_SYS_CLOCK_KHZ, (unsigned)(sys / 1000));
    }
#endif

#if defined(SPICOMPUTER_HAS_HDMI)
    uint32_t div, hstx, pixel;
    bool warn;
    video_hw_clock_info(&div, &hstx, &pixel, &warn);
    sd_log("HSTX: clk_sys %u / %u = %u Hz (pixel clock %u Hz)",
           (unsigned)sys, (unsigned)div, (unsigned)hstx, (unsigned)pixel);
    if (warn) {
        sd_log("HSTX: warning: clk_sys does not divide to a 25.2 MHz "
               "pixel clock; expect ~%u Hz refresh",
               (unsigned)(pixel /
                          (SCANOUT_H_TOTAL_PIXELS * SCANOUT_V_TOTAL_LINES)));
    }
#endif
}

void core1_entry(void)
{
    /* stdio first, so the boot log below is visible. The clock was set by
     * core 0 before this core was launched, so baud rates are correct. */
    stdio_init_all();
    boot_signal(5); /* stdio up: USB should be enumerating */

    /* Arm the watchdog before anything that could hang (the boot prints,
     * the SD mount, the first program load). Nothing feeds it until the
     * scheduler loop below, so a hang anywhere in boot resets the board
     * and it retries - a bad boot can never leave the board silent and
     * unreachable. The period is generous here because a slow card can
     * take seconds to answer. */
    bool was_watchdog = watchdog_caused_reboot();
    watchdog_enable(8000, 1);
    watchdog_update();

    /* Buffered until the card is mounted, then flushed below. */
    log_reset_reason(was_watchdog);
    print_boot_info();

    /* Filesystem: the SD card is on this core now, so the Lua bindings
     * call straight into the FatFs layer with no cross-core round trip.
     * The video core claimed its DMA channels and DMA_IRQ_2 before this
     * core started, so the SD driver gets its own. */
    rpc_set_local_handler(fs_service);
    bool card_ok = false;
#if defined(SPICOMPUTER_VIDEO_TEST_PATTERN) || defined(SPICOMPUTER_CHEQUERBOARD)
    /* Test pattern builds deliberately perform no SD work: this isolates
     * the video core from card-init traffic, DMA and XIP activity. */
    printf("test pattern build: SD mount skipped (no SD log)\n");
#else
    card_ok = fs_core0_mount();
    if (card_ok) {
        sd_log("boot: SD card mounted");
        sd_log_flush();
    } else {
        printf("SD card not mounted (no SD log)\n");
    }
#endif
    /* The mount is the slow, unbounded part of boot (an empty socket can
     * cost a full command timeout); give the program load its own full
     * watchdog period rather than whatever the card left of this one. */
    watchdog_update();
    boot_signal(6); /* card stage complete */

    /* Input subsystem: 1 kHz matrix and joystick scanning. This claims
     * the alarm pool (and its IRQ) for this core. */
    input_hw_init();

    bool boot_failed = false;
#if defined(SPICOMPUTER_VIDEO_TEST_PATTERN)
    /* Diagnostic build: the scanout draws a test pattern, so no program
     * is loaded (the SD mount above still reports the card). */
    printf("test pattern build: boot program not loaded\n");
#elif defined(SPICOMPUTER_CHEQUERBOARD)
    /* Forced chequerboard: the card is never read and no Lua runs, so
     * whatever the monitor shows is the HDMI path alone. */
    video_hw_set_test_pattern(true);
    printf("chequerboard build: boot program not loaded\n");
#else
    /* No card, or a card without a boot program: show the chequerboard
     * instead of a black screen, so a missing card and a dead display
     * look different on the bench. */
    if (!card_ok) {
        boot_failed = true;
        video_hw_set_test_pattern(true);
        printf("no SD card: showing the chequerboard test pattern\n");
    } else if (!program_boot(BOOT_SCRIPT, NULL)) {
        boot_failed = true;
        video_hw_set_test_pattern(true);
        sd_log("boot: %s failed (details in logs/errors); showing the "
               "chequerboard", BOOT_SCRIPT);
    } else {
        sd_log("boot: %s running", BOOT_SCRIPT);
    }
    sd_log_flush();
#endif
    boot_signal(7); /* boot program attempted; scheduler loop next */

    /* Boot is over: from here the loop below is the only thing feeding
     * the watchdog, so a stuck VM, a deadlock or a frozen display resets
     * the system. */
    watchdog_enable(2000, 1);
    watchdog_update();

    uint32_t last_frames = g_system_state.video_frame_count;
    uint64_t last_frame_us = time_us_64();
    uint64_t boot_us = last_frame_us;
    uint64_t stats_us = last_frame_us;
    uint32_t last_underruns = 0;
    uint32_t last_long_gaps = 0;
    bool stall_logged = false;

    for (;;) {
        /* Drain input, run due timers, otherwise tick. */
        crumb_phase(PHASE_SCHEDULER);
        program_scheduler_step();
        audio_service(); /* stream a playing module's samples from the card */
        crumb_phase(PHASE_LOOP);

        /* An empty program stack means the last program (a game that
         * replaced the shell, or the shell itself) has exited: there is
         * nothing left to run, so restart the machine cleanly. */
        if (!boot_failed && program_top() == NULL) {
            sd_log("program stack empty: rebooting");
            crumb_phase(PHASE_LOG);
            sd_log_flush();
            watchdog_reboot(0, 0, 0);
            for (;;) {
                tight_loop_contents();
            }
        }

        uint64_t now = time_us_64();
        uint32_t frames = g_system_state.video_frame_count;
        if (frames != last_frames) {
            last_frames = frames;
            last_frame_us = now;
        }

#if defined(SPICOMPUTER_HAS_HDMI)
        if (boot_failed) {
            watchdog_update();
        }
        /* Two liveness gates: this loop is running (a stuck VM or a
         * deadlock stops the scheduler step above) and the display is
         * producing frames. On boards without HSTX only the first
         * applies; the frame counter never moves there. */
        bool video_alive = (now - boot_us < VIDEO_BOOT_GRACE_US) ||
                           (now - last_frame_us < VIDEO_STALL_LIMIT_US);
        if (video_alive && !boot_failed) {
            watchdog_update();
        }
        if (!video_alive && !stall_logged) {
            /* The watchdog resets the board in 2 s: get this onto the
             * card first. */
            stall_logged = true;
            sd_log("video: FRAME COUNTER STALLED at frame %lu (scanline "
                   "%lu); the watchdog will reset the board",
                   (unsigned long)frames, (unsigned long)video_hw_scanline());
            crumb_phase(PHASE_LOG);
            sd_log_flush();
            crumb_phase(PHASE_LOOP);
        }
#else
        (void)boot_us;
        (void)last_frame_us;
        watchdog_update();
#endif

        if (now - stats_us >= LOG_PERIOD_US) {
            stats_us = now;
            boot_signal_tick(); /* alive: status-LED blink */
            uint32_t up_s = (uint32_t)(now / 1000000u); /* since reset */
            watchdog_hw->scratch[CRUMB_SCRATCH_UPTIME] = up_s;
#if defined(SPICOMPUTER_HAS_HDMI)
            /* One line per period. Every counter is cumulative, so a
             * dropout that leaves them all flat (with `up` still
             * counting) was not caused by the scanout. */
            uint32_t underruns = video_hw_underruns();
            sd_log("t=%lus frame=%lu underruns=%lu(+%lu) skew=%lu(%lu) "
                   "gap_max=%luus long=%lu empty=%lu wof=%lu late=%lu "
                   "fifo_min=%lu",
                   (unsigned long)up_s, (unsigned long)frames,
                   (unsigned long)underruns,
                   (unsigned long)(underruns - last_underruns),
                   (unsigned long)video_hw_skews(),
                   (unsigned long)video_hw_last_frame_steps(),
                   (unsigned long)video_hw_gap_max_us(),
                   (unsigned long)video_hw_long_gaps(),
                   (unsigned long)video_hw_fifo_empty(),
                   (unsigned long)video_hw_fifo_wofs(),
                   (unsigned long)video_hw_late_posts(),
                   (unsigned long)video_hw_fifo_min());
            uint32_t long_gaps = video_hw_long_gaps();
            if (long_gaps != last_long_gaps) {
                sd_log("  last long gap: %luus ending at frame %lu line %lu, "
                       "fifo %lu, cmdlist next %lu, underruns %lu",
                       (unsigned long)video_hw_last_gap_us(),
                       (unsigned long)video_hw_last_gap_frame(),
                       (unsigned long)video_hw_last_gap_line(),
                       (unsigned long)video_hw_last_gap_fifo_level(),
                       (unsigned long)video_hw_last_gap_cmdlist(),
                       (unsigned long)video_hw_last_gap_underruns());
                last_long_gaps = long_gaps;
            }
            last_underruns = underruns;
            /* Core 0's row renderer: how much of the 63.5 us row it
             * uses. Sprites and the audio pump spend from this margin. */
            uint32_t rows, sum_us, max_us;
            video_hw_render_stats(&rows, &sum_us, &max_us, true);
            uint32_t avg_x10 = rows ? (sum_us * 10u) / rows : 0;
            sd_log("render: rows=%lu avg=%lu.%luus max=%luus (row budget "
                   "63us)",
                   (unsigned long)rows, (unsigned long)(avg_x10 / 10),
                   (unsigned long)(avg_x10 % 10), (unsigned long)max_us);
#else
            sd_log("t=%lus", (unsigned long)up_s);
#endif
            /* Time inside Lua this period: a max well above the average
             * is a slow tick or a GC stall; heap is the top program's
             * Lua allocation against its cap. */
            program_lua_stats_t ls;
            program_lua_stats(&ls, true);
            program_t *top = program_top();
            sd_log("lua: calls=%lu avg=%luus min=%luus max=%luus busy=%lu%% "
                   "pid=%ld heap=%lu/%luKB",
                   (unsigned long)ls.calls,
                   (unsigned long)(ls.calls ? ls.total_us / ls.calls : 0),
                   (unsigned long)ls.min_us, (unsigned long)ls.max_us,
                   (unsigned long)(ls.total_us * 100u / LOG_PERIOD_US),
                   top ? (long)top->pid : -1L,
                   (unsigned long)(top ? top->heap_used / 1024u : 0),
                   (unsigned long)(top ? top->heap_cap / 1024u : 0));
            crumb_phase(PHASE_LOG);
            sd_log_flush();
            crumb_phase(PHASE_LOOP);
        }
    }
}

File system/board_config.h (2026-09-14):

/* board_config.h
 *
 * Board selection for the SPIComputer OS.
 *
 * The platform define (PICO_RP2350 / PICO_RP2040) is set automatically by
 * the pico-sdk from the selected PICO_BOARD / PICO_PLATFORM, and doubles as
 * the capability switch:
 *
 *   - RP2040 dev board (default): SD card only.
 *   - RP2354B product board: adds HDMI (HSTX), C64 key matrix, joysticks.
 *
 * Pin assignments are package-correct per platform.
 */
#pragma once

#if defined(PICO_RP2350)

/* ==================== RP2350 boards ==================== */

#define SPICOMPUTER_HAS_HDMI 1

/* Target CPU clock (core0/main.c applies it before anything else runs;
 * core 1 reports the result in the boot log).
 *
 * The value must divide (through the HSTX's 1..3 clock divider) to
 * 126 MHz so the pixel clock stays the exact 25.2 MHz: 252 MHz (/2) and
 * 378 MHz (/3) both do, and both keep the flash clock within its boot
 * range (core0/main.c rescales the QMI divider). The default is the
 * known-good 252 MHz (2x): a 378 MHz build (1.30 V) produced no HDMI
 * sync at all on the pico2 prototype, and the display must be proven
 * before the clock is pushed again. 378 MHz remains the highest clock
 * that keeps the DVI timing exact; 400 MHz and above run on the silicon
 * but cannot be divided to 25.2 MHz (400/3 = 133.3 MHz, i.e. 26.7 MHz
 * pixels and ~63.5 Hz refresh, off spec), and clk_hstx cannot borrow
 * pll_usb either, because USB stdio pins that PLL to 48/96/144 MHz.
 *
 * Build with -DSPICOMPUTER_SYS_CLOCK_KHZ=<khz> to override; the clock is
 * applied by core0/main.c before anything else runs and reported in the
 * boot log. */
#ifndef SPICOMPUTER_SYS_CLOCK_KHZ
#define SPICOMPUTER_SYS_CLOCK_KHZ 252000
#endif

#define HSTX_D0_P_PIN 12
#define HSTX_D0_N_PIN 13
#define HSTX_CLK_P_PIN 14
#define HSTX_CLK_N_PIN 15
#define HSTX_D2_P_PIN 16
#define HSTX_D2_N_PIN 17
#define HSTX_D1_P_PIN 18
#define HSTX_D1_N_PIN 19

#if defined(SPICOMPUTER_PROFILE_RP2354B)
#define SPICOMPUTER_HAS_KEYMATRIX 1
#define SPICOMPUTER_HAS_JOYSTICKS 1
#define SPICOMPUTER_HAS_RESTORE 1
#endif

/* The pico2 dev board's onboard LED makes boot progress observable
 * without a console. Only for that profile: on the product board the
 * same pin is a keyboard column. */
#if defined(SPICOMPUTER_PROFILE_PICO2) && !defined(SPICOMPUTER_HAS_KEYMATRIX)
#define SPICOMPUTER_HAS_BOOT_LED 1
#define SPICOMPUTER_BOOT_LED_PIN PICO_DEFAULT_LED_PIN
#endif

/* SD card on SPI1. HSTX uses the explicit differential GPIO pairs above;
 * SPI1 uses RX=GP8, CSn=GP9, SCK=GP10, TX=GP11. */
#define SD_SPI_INSTANCE spi1
#define SD_PIN_SCK 10
#define SD_PIN_MOSI 11
#define SD_PIN_MISO 8
#define SD_PIN_CS 9

/* External SPI bus (SPI0) for expansion drives/peripherals.
 * Pins defined for the board layout; no driver yet. */
#define EXT_SPI_INSTANCE spi0
#define EXT_SPI_SCK_PIN 2
#define EXT_SPI_MOSI_PIN 3
#define EXT_SPI_MISO_PIN 0
#define EXT_SPI_CS_PIN 1

/* USB: the RP2350 USB PHY uses dedicated package pins (no GPIOs), so
 * the board can expose a USB connector for flashing without spending
 * any of the 48 GPIOs. */

/* C64 keyboard matrix: 8 columns read, 8 rows driven, plus RESTORE.
 * Active-low like the original C64 (row driven low, columns pulled up).
 * Wired in logical order per the keyboard connector: COL0-7 on GP20-27,
 * ROW0-7 on GP28-35, RESTORE on GP36. */
#define KB_ROWS 8
#define KB_COLS 8
#define KB_COL_PIN(col) (20 + (col)) /* read lines, C64 PB0-7 order */
#define KB_ROW_PIN(row) (28 + (row)) /* driven lines, C64 PA0-7 order */
#define RESTORE_PIN 36 /* active low, pulled up */

/* Two DSUB9 digital joysticks, active-low (switch to GND, pulled up):
 * up/down/left/right/fire. Dirs on GP37-40 (stick 1) and GP43-46
 * (stick 2); fires on GP6/GP7. GP47 (XIP_CS1n) stays free. */
#define JOY1_UP_PIN 37
#define JOY1_DOWN_PIN 38
#define JOY1_LEFT_PIN 39
#define JOY1_RIGHT_PIN 40
#define JOY1_FIRE_PIN 6
#define JOY2_UP_PIN 43
#define JOY2_DOWN_PIN 44
#define JOY2_LEFT_PIN 45
#define JOY2_RIGHT_PIN 46
#define JOY2_FIRE_PIN 7

#else

/* ==================== RP2040 dev board (default) ==================== */

/* SD card on SPI1 (standard Pico SPI1 pins). */
#define SD_SPI_INSTANCE spi1
#define SD_PIN_SCK 10
#define SD_PIN_MOSI 11
#define SD_PIN_MISO 12
#define SD_PIN_CS 13

#endif

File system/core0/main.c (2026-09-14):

/* core0/main.c
 *
 * Core 0: the video core. After the core split this core does one thing:
 * the HSTX scanout. It brings the display up (TMDS expansion, the DMA
 * ping/pong chain, the render pump) and then idles in WFI while those
 * IRQs feed the display from core 0's screen slots (see video.h); core 1
 * only queues display ops for this core to apply at frame boundaries.
 *
 * Everything else - stdio, the SD card and FatFs, input scanning, the
 * watchdog and the Lua scheduler - runs on core 1 (core1/lua_main.c),
 * which this file launches. Nothing here may touch stdio (the OS core
 * owns it) and nothing here may use the alarm pool: sleep_ms()/timers
 * would claim the shared timer IRQ for this core and steal the OS core's
 * input tick. The one cross-core object is the frame counter in
 * g_system_state, which the scanout writes.
 */

#include "pico/bootrom.h"
#include "pico/stdlib.h"
#include "pico/multicore.h"
#include "hardware/clocks.h"
#include "hardware/spi.h"
#include "hardware/structs/qmi.h"
#include "hardware/vreg.h"
#include "hardware/xip_cache.h"

#include "board_config.h"
#include "boot_signal.h"
#include "video_hw.h"

/* Core 1 entry point (defined in core1/lua_main.c) */
extern void core1_entry(void);

/* Core 1's stack. The SDK's default core-1 stack lives in SCRATCH_X,
 * which is only 4 KB on this chip; the OS core runs stdio, FatFs and the
 * Lua VM, so it gets a larger stack in main SRAM instead. */
#define CORE1_STACK_BYTES (16 * 1024)
static uint32_t __attribute__((aligned(8)))
    s_core1_stack[CORE1_STACK_BYTES / sizeof(uint32_t)];

/* Placeholder display SPI (the generated example's SPI0 wiring).
 * GP16-19 are HSTX lanes on RP2350, so this only exists on boards
 * without HDMI. */
#if !defined(SPICOMPUTER_HAS_HDMI)
#define SPI_PORT spi0
#define PIN_MISO 16
#define PIN_CS   17
#define PIN_SCK  18
#define PIN_MOSI 19
#endif

/* ------------------------------------------------------------------ */
/* CPU overclock                                                      */
/*                                                                    */
/* RP2350 only: the QMI flash timing and the HSTX clock divider it     */
/* has to work with are RP2350 peripherals.                           */
/* ------------------------------------------------------------------ */

#if defined(PICO_RP2350)

/* 150 MHz is the stock clock, so any overclock needs more core voltage.
 * 1.25 V is comfortable for 252 MHz; the default 378 MHz (and anything
 * above 300 MHz) gets 1.30 V, the highest setting the SDK allows without
 * unlocking the regulator. */
#if SPICOMPUTER_SYS_CLOCK_KHZ > 300000
#define SPICOMPUTER_OC_VOLTAGE VREG_VOLTAGE_1_30
#else
#define SPICOMPUTER_OC_VOLTAGE VREG_VOLTAGE_1_25
#endif

/* The QSPI read command the boot stage selected in QMI M0 (0x03, 0x0B,
 * 0xBB or 0xEB). */
static uint32_t xip_read_cmd(void) {
    return (qmi_hw->m[0].rcmd & QMI_M0_RCMD_PREFIX_BITS) >>
           QMI_M0_RCMD_PREFIX_LSB;
}

static bool xip_read_mode(uint32_t cmd, bootrom_xip_mode_t *mode) {
    switch (cmd) {
        case 0x03: *mode = BOOTROM_XIP_MODE_03H_SERIAL; return true;
        case 0x0b: *mode = BOOTROM_XIP_MODE_0BH_SERIAL; return true;
        case 0xbb: *mode = BOOTROM_XIP_MODE_BBH_DUAL; return true;
        case 0xeb: *mode = BOOTROM_XIP_MODE_EBH_QUAD; return true;
        default: return false;
    }
}

/* Scale the flash clock with clk_sys.
 *
 * The boot stage runs the QSPI flash at clk_sys/PICO_FLASH_SPI_CLKDIV
 * (150/2 = 75 MHz on this board). Raising clk_sys without touching that
 * would overclock the flash, so the flash divider and its sampling delay
 * are re-programmed first, while the system clock is still low.
 *
 * The preferred path hands the work to the bootrom
 * (rom_flash_select_xip_read_mode): it re-applies the mode's complete
 * timing table (divider, cooldown, RX delay) for the new divider - the
 * same table it used to bring the flash up at boot - so the sampling
 * point is right rather than approximated. The fallback scales the
 * divider and keeps the boot RXDELAY/divider ratio, which is the
 * proportional part of the same calculation (RXDELAY is in half clk_sys
 * cycles, so the delay for a given sample point scales with the
 * divider).
 *
 * This must run from SRAM: XIP timing is in flux across the change, and
 * the cache is flushed after. Interrupts are still off at this point. */
static void __no_inline_not_in_flash_func(flash_scale_clock)(
    uint32_t old_khz, uint32_t new_khz) {
    uint32_t timing = qmi_hw->m[0].timing;
    uint32_t div =
        (timing & QMI_M0_TIMING_CLKDIV_BITS) >> QMI_M0_TIMING_CLKDIV_LSB;

    /* Round the divider up so the flash never runs faster than at boot. */
    uint32_t new_div = (div * new_khz + old_khz - 1) / old_khz;
    if (new_div < 1) new_div = 1;
    if (new_div > 0xffu) new_div = 0xffu;

    bootrom_xip_mode_t mode;
    if (xip_read_mode(xip_read_cmd(), &mode)) {
        rom_flash_select_xip_read_mode(mode, (uint8_t)new_div);
        xip_cache_invalidate_all();
        return;
    }

    /* Unknown read mode: scale the divider and the RX delay ourselves. */
    uint32_t rx =
        (timing & QMI_M0_TIMING_RXDELAY_BITS) >> QMI_M0_TIMING_RXDELAY_LSB;
    uint32_t new_rx = div ? (rx * new_div + div - 1) / div : rx;
    if (new_rx > 7u) new_rx = 7u;
    qmi_hw->m[0].timing =
        (timing & ~(QMI_M0_TIMING_CLKDIV_BITS | QMI_M0_TIMING_RXDELAY_BITS)) |
        (new_div << QMI_M0_TIMING_CLKDIV_LSB) |
        (new_rx << QMI_M0_TIMING_RXDELAY_LSB);
    xip_cache_invalidate_all();
}

/* Bring clk_sys up to SPICOMPUTER_SYS_CLOCK_KHZ, or down to 126 MHz if
 * that is not achievable, or leave it alone. Returns the clock in use;
 * the OS core reports the result against the request (it owns stdio). */
static uint32_t apply_sys_clock(void) {
    uint32_t old_khz = clock_get_hz(clk_sys) / 1000;
    uint32_t want = SPICOMPUTER_SYS_CLOCK_KHZ;
    uint vco, postdiv1, postdiv2;

    if (!check_sys_clock_khz(want, &vco, &postdiv1, &postdiv2)) {
        want = 126000; /* the exact 25.2 MHz pixel clock source */
        if (!check_sys_clock_khz(want, &vco, &postdiv1, &postdiv2)) {
            return clock_get_hz(clk_sys);
        }
    }
    if (want > old_khz) {
        vreg_set_voltage(SPICOMPUTER_OC_VOLTAGE);
        /* Let the regulator settle. A busy wait, not sleep_ms(): sleeping
         * would claim the shared timer IRQ for this core and starve the
         * OS core's 1 kHz input tick. */
        busy_wait_us(10000);
        flash_scale_clock(old_khz, want);
    }
    /* Note: this also moves clk_peri to the 48 MHz USB clock (the SDK
     * default for a PLL change), which is what the SD SPI driver's
     * divider is computed from. */
    set_sys_clock_pll(vco, postdiv1, postdiv2);
    return clock_get_hz(clk_sys);
}

#endif /* PICO_RP2350 */
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

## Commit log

2026-09-09 Add SPIComputer OS firmware with dual-core split and host tests
    Phase 0 of the OS plan: the firmware image now runs the hardware
    subsystems on core 0 and the Lua engine on core 1, with board pin
    assignments selected by platform (RP2040 dev board vs RP2354B product
    board). Includes the vendored Lua 5.5 core and FatFs SD-card driver,
    the Lua file-system bridge, and a host-test target that exercises the
    bridge without hardware.
2026-09-09 remove circuit plan
    [SPIComputer.kicad_pcb, SPIComputer.kicad_sch, freerouting.dsn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]
2026-09-11 Add audio engine, desktop simulator and IDE; rename OS to os
    The OS gets its Phase 8 audio subsystem: an 8-voice stereo synth with
    envelopes, a looping multi-channel score player and WAV sample playback,
    exposed to Lua as Sound*/Music* and owned per program like video state.
    A new desktop simulator runs the real OS sources against a `sdcard`
    folder, replacing SD, video, audio and input with SDL implementations so
    programs can be developed and tested without hardware. A SwiftUI IDE
    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
2026-09-13 IDE runtime error handling
    [board_config.h]
2026-09-14 Remove automatic test pattern fallback on failed boot
    A failed SD mount or boot program load no longer switches the display
    to the bring-up pattern; the screen stays black until a program owns
    it again. The build-time diagnostic pattern (video test pattern build)
    is unchanged.
    [lua_main.c]
2026-09-14 Default the display to 50 Hz vertical timing
    The pixel clock stays 25.2 MHz, so using 800x630 instead of 800x525
    lines gives exactly 50 Hz and grows the vblank window from 1.4 ms to
    4.8 ms, leaving core 0 more time between frames and 17% less line
    rendering per second. Build with -DSPICOMPUTER_REFRESH_HZ=60 for the
    standard VESA timing; scanout remains the only place the rate is set.
2026-09-14 Move the display state onto core 0 with a queued change list
    Lua-driven drawing copied a full 32 KB screen snapshot (plus the mode-10
    framebuffer) into core 0 every frame while the scanout line ring held
    only a few hundred microseconds of data, so any busy update stalled the
    stream. Core 0 now owns one screen per program slot and core 1 only
    queues small ops, drained at each frame boundary, which removes the
    copies and frees ~90 KB of RAM.
    The 80-column modes are retired for now: every mode is 320x240 logical,
    doubled to 640x480, and programs keep their screen across launches
    because the slots live on.
    Note: pushed history is the rollback point - revert this commit to get
    the snapshot pipe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
    [lua_main.c, main.c]
2026-09-14 Replace the layered screen with a base layer and one overlay
    Drawing on stacked z-ordered layers cost a per-cell layer loop in the
    renderer and 4.8 KB per screen slot for layers that were rarely all in
    use. There is now a base layer plus a single composited overlay:
    ScreenOut/ScreenAttr/ScreenClear draw the base, and the new
    OverlayOut/OverlayAttr/OverlayClear draw the overlay, whose cells stay
    hidden until written.
    ScreenZOrder is gone, so card programs that call it need updating; the
    in-repo boot component has been migrated but its generated card files
    still need a rebuild from the IDE.
2026-09-14 Add Launch(..., replace) and rebuild the boot screen on timers
    Launch could only stack a new program on top of the caller, so a boot
    loader had to stay resident (holding its Lua state and screen slot) for
    the whole session even after the shell started. With replace true the
    new program takes the caller's place on the stack and the caller's Lua
    state, timers and audio are released once its current call returns;
    finish() still runs.
    The boot program now uses that handover and runs its startup screen from
    a 150 ms timer instead of tick(), so the scheduler idles between updates
    rather than calling into it thousands of times a second.
2026-09-14 Add a chequerboard test pattern and fix the 60-line frame rebase
    The scanout was told each frame had 30 logical rows (the tile row
    count) instead of 240 pixel rows, so it declared the frame over every
    60 output lines: the rest of the picture repeated the last row as
    underruns and the display change queue was drained mid-frame. Use the
    pixel row count.
    A colour chequerboard can now be shown instead of the program screen,
    so the HDMI path can be judged with no card, no Lua and no breadboard
    SD wiring involved. It appears automatically when no card is present
    or the boot program cannot start, and -DSPICOMPUTER_CHEQUERBOARD=ON
    forces it on and skips the card entirely.
    [lua_main.c]
2026-09-14 Run the CPU at 378 MHz by default
    378 MHz is the highest clock that still divides to the exact 25.2 MHz
    DVI pixel clock (clk_hstx = clk_sys / 3); 400 MHz would put the pixel
    clock 6% off spec, which is the wrong direction for a monitor that is
    already struggling to hold sync.
    [board_config.h, main.c]
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2026-09-14 Fail the SD mount quickly when no card is present
    With an empty socket the data line can read as a card that is
    permanently busy, so every command first waited its full 2 s timeout
    and the CMD0 retry loop alone took over 20 s: the boot watchdog fired
    before the mount could report failure, so the board rebooted in a loop
    instead of showing the chequerboard. A command whose ready-wait times
    out now reports "no device" and the init sequence stops retrying, and
    the program load gets a fresh watchdog period after the mount.
    [lua_main.c, sd_card.c]
2026-09-14 Fix SD ready detection on the RP2350
    [sd_card.c]
2026-09-14 Keep the fallback pattern alive after boot failure
    [lua_main.c]
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2026-09-14 Keep core 0's scanout path out of flash
    The HSTX command lists were static const, so they were linked into flash
    and the video DMA read them through the XIP cache that both cores share.
    Once a Lua program ran on core 1, the interpreter evicted them. The DMA
    then stalled on QSPI refills while the 8-word HSTX FIFO drained, and the
    stretched lines made the monitor drop sync as soon as Lua drew anything.
    The chequerboard stayed clean because core 1 was idle and left the cache
    warm.
    Move the command lists, the render pump and its idle loop, the RGB332
    renderer (with an SRAM copy of the ROM font), the op drain and the
    chequerboard table into SRAM. The drain uses its own fill loop instead
    of the f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
    [main.c]
2026-09-14 Detect late DMA posts and log uptime in the video status
    The status line could not prove the TMDS stream was intact: `empty`
    samples a live FIFO flag at IRQ time, and nothing caught the one way a
    slow IRQ corrupts a line. That happens when the chain re-triggers a
    channel before its next buffer is posted, and the channel then replays
    stale data into HSTX. Count those (the channel is already busy at post
    time) and keep a low-water mark of the HSTX FIFO level. Print uptime
    too, so a watchdog reset is obvious in the log. If the monitor drops
    sync while all of these stay flat, the fault is electrical.
    Claude-Session: https://clau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
    [lua_main.c]
2026-09-14 Log boot and video status to spilog.txt on the SD card
    USB stdio is not usable on the bench, so the diagnostics need to reach
    the card. Core 1 buffers log lines in RAM and appends them to spilog.txt
    once per status period, using one open/append/close per write so that
    nothing already flushed is lost to a reset.
    Each boot records the POWMAN reset reason (power-on, brown-out, RUN pin,
    watchdog, ...). It also records the previous run's uptime and loop phase
    from breadcrumbs kept in watchdog scratch 0-2. A frame-counter stall is
    flushed immediately, before the watchdog fires. Together these tell a
    reset loop apart from a monitor that loses lock on an intact stream.
    Also implement fs_core0_moun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
    [lua_main.c]
2026-09-14 Add Lua and render timing to the status log, plus a benchmark app
    Baseline instrumentation before any Lua engine change, so each one can
    be judged by a number rather than by feel.
    Core 1 times every Lua callback (tick, timer, input callbacks, setup,
    finish) and the status log prints calls, average/min/max and percent
    busy per period, with the top program's heap use against its cap. Core
    0 times every row render and reports rows, average and worst row time
    against the 63.5 us row budget: the margin that sprites or an audio
    pump would spend from.
    software/bench is a SPIEdit project (app `bench`) that runs one fixed-
    size test per tick - integer and float loops, Lua calls, table array
    and has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
    [lua_main.c]
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2026-09-14 Add block display ops and look up input callbacks per event
    Fill, Box, Copy, Move, Scroll, FillAttr, Write and WriteAttr (and their
    Overlay twins) each queue one op, whatever the rectangle's size; core 0
    applies them at the frame boundary in video.c. Before, a fill or a box
    was one op per cell, so a full-screen repaint blocked for more than a
    frame's queue. Write carries its bytes through a two-slot staging
    buffer: the producer reuses a slot only after the drain has applied the
    op that referenced it, which is why the drain now applies an op before
    advancing the head. Move handles an overlapping destination and blanks
    only the part of the source the block no longer covers. ScreenLoadImage
    is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
2026-09-14 Add selectable frameworks (SDKs) to the IDE with dead-function stripping
    Four read-only Lua frameworks ship inside SPIIDECore's resources and can
    be selected per project (new projects select them all): Screen and
    Overlay (text, windows, dialogs, fills, block moves and scrolls over the
    block display ops, with inclusive-corner region calls), Sound/Music
    (tones, beeps and noise without defining instruments, plus the score
    API) and Input (keyboard and joystick callbacks by key or action, key
    code names). They are injected after the __spi_* flags and before the
    components.
    The builder reads a framework as a preamble plus column-0 function
    blocks and emits only the blocks the program's code menti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
2026-09-15 Select every framework by default and add Screen.OutLine
    Projects saved before frameworks existed have no `sdks` key, and the
    decoder read that as "none", so the editor knew nothing about Screen,
    Overlay, Sound or Input in any existing project: no completion, no
    parameter help, and a build that left the namespaces undefined. A
    missing key now selects every framework (stripping keeps the unused
    ones out of the built program), while an explicit empty list still
    opts out. Tests pin dotted-name completion and parameter help in the
    real editor and the manifest default.
    Screen.OutLine(text [, attr]) is the console-style call: it writes on
    the cursor row, advances, wraps long text and scrolls the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
2026-09-15 Stop background checks and runtime errors moving the caret or component
    Two things pulled the user away from what they were typing. A runtime
    error from the running simulator switched the selected component to
    the one the error mapped to, mid-keystroke. And every time a background
    check changed the diagnostic line, the editor scrolled to it, which for
    an incomplete line such as "Screen.O" is wherever Lua reported the next
    token, often far from the caret or in another component's span.
    Navigation is now explicit. Background checks only mark the line in the
    gutter and banner; "Go to Line" on a banner places the caret. The
    runtime error banner appears above whichever component is being edited,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
2026-09-15 Add utilities that return tables, games that own the machine, and reboot on an empty stack
    Three additions to the process model and the shell:
    UtilityResult(ok, value) now accepts a table as well as a string. The
    table is serialised to Lua source in the utility's state (strings,
    numbers, booleans, nested tables with string or integer keys; anything
    else becomes nil; 8 KB cap) and rebuilt in the caller's state by
    UtilityPoll, so a utility hands structured results back. Results are
    heap-allocated and handed from child to parent instead of living in
    fixed 256-byte buffers. The shell prints a table's message field first
    and the rest as KEY = VALUE, and resolves a command name to
    utils/<name>.ut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
    [lua_main.c]
2026-09-15 Simulator: restart on an empty stack, real-time frames, --type-delay-ms
    The device reboots when the last program exits; the simulator now
    restarts its boot program instead of running on with nothing to tick.
    The frame counter follows wall-clock time at 60 Hz, advanced per frame
    and from inside WaitVSync's wait: it was never advanced at all, so a
    program waiting for frames each tick timed out at 100 ms per tick and
    one 64-tick frame took 6.4 s. --type-delay-ms sets how long scripted
    typing waits after boot (keys typed while boot.lua shows its splash go
    to the splash's input ring and are lost with it).
    Claude-Session: https://claude.ai/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
2026-09-15 Card projects build into their own folders; add hello, spin and install.sh
    The generated core/ and apps/ outputs leave the repository: each
    project builds into its own build/ (ignored), and software/install.sh
    builds every project and assembles a card image in software/sdcard/
    (also ignored) with core/, apps/, utils/, games/ and data/. Manifests
    move to format 2 kinds: os and boot are raw programs installed to
    core/, the others applications. Two small examples cover the new
    kinds: hello (a utility that returns a table) and spin (a game). The
    boot program loses a stray "Screen." line that broke its build.
    Claude-Session: https://claude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
2026-09-15 Editor: rewrite on the Screen/Overlay/Text/Timer frameworks
    The editor still called ScreenZOrder and the retired 80-column mode, so
    it failed at setup. It now keeps only the text on the base layer (menu
    bar on row 0, text rows 1-28, Screen.Label status bar) and puts the
    drop-down menus and every dialog on the overlay as Overlay.Window /
    Overlay.Dialog, so opening and closing them is an Overlay.Clear with no
    text redraw. The cursor is the invert attribute on its cell, blinked by
    Timer.Every and paused while the overlay is up; keys arrive through
    on_keypress. Menus keep FILE / EDIT / OPTIONS / HELP with the same key
    bindings; the 40/80 toggle is replaced by a file-info dialog and the
    quit prom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
2026-09-15 Screen SDK: name the attribute colours in an Attributes namespace
    Attributes.White/Red/Cyan/Purple/Green/Blue/Yellow/Orange are the mode-1
    palette colour indexes and Attributes.Inverse the invert bit, so a
    program writes Attributes.Red + Attributes.Inverse instead of 0x81. The
    SDK parser now records the preamble's `Name.CONST = value` lines as
    constants: they complete in the editor without a parameter list, a
    program that only reads them still gets the framework preamble, and the
    help test requires an entry for every one (added for Attributes, with a
    namespace entry).
    Claude-Session: https://claude.ai/code/session_01DCX1PoKjSLNwrMubnX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
2026-09-15 Add breakout, a game drawn with coloured attribute cells
    Walls, six rows of bricks and the paddle are inverted spaces coloured
    with the Attributes constants, so a brick row is one Screen.Fill and a
    hit is one Fill back to normal; the ball is a glyph moved in fractional
    cell steps with only the changed cells redrawn. Paddle from the cursor
    keys, Z/X or joystick 1 (taps step a cell, holding glides), SPACE/fire
    serves, levels speed up, game over offers a restart, ESC exits (the
    device restarts). Paced by WaitVSync; tones from the Sound framework.
    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
2026-09-15 Simulator: end a frame's tick batch when the frame clock moves on
    A frame ran up to 64 scheduler steps before rendering and polling SDL.
    A game that paces tick() with WaitVSync spends each step waiting for the
    next 60 Hz frame, so a simulator frame lasted about a second: breakout
    drew and read keys roughly once a second while its logic ran at speed.
    The batch now stops as soon as the frame clock advances, pacing sleeps
    to the next frame boundary instead of a fixed 16 ms after the render,
    and the WaitVSync hook sleeps through most of the wait instead of
    spinning. Breakout goes from ~1 to 60 rendered frames a second; the
    shell still gets its 64 ticks per frame. The exit summary now reports
    fra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
2026-09-15 Video: stage text in a 4 KB byte ring instead of two screen slots
    ScreenWrite/OverlayWrite bytes travelled through two whole-screen
    staging slots, and a slot came free only when core 0 applied its op at
    the next vblank drain. The third text write in any frame therefore
    stalled core 1 for up to a frame: breakout's HUD cost a frame per brick,
    and a 28-line editor redraw about 14 frames per keystroke. Each write
    now takes just its bytes from a ring, the op's `e` carries their
    free-running end, and core 0 releases them as it applies the op, so core
    1 waits only when 4 KB of text is still unapplied. The op queue itself
    stays lock-free. The drain remains flash-free (checked in the image:
    no flash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
2026-09-15 IDE: vendor the simulator with the per-frame tick batch fix
    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
2026-09-15 Simulator: --dump-text writes the final screen as text
    Thirty lines of forty characters with the overlay composited on top,
    '#' for codes outside printable ASCII, and a '^' marker under inverted
    cells, so scripted runs can check a screen with grep instead of reading
    a PPM.
    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
2026-09-15 fs.ls: report a folder that cannot be opened instead of listing nothing
    pack_ls returned zero entries when f_opendir failed and left the
    response's result at FR_OK, so fs.ls of a missing folder answered with
    an empty list (on the board and in the simulator). The LS request now
    carries the open error and fs.ls returns nil, err. The host mock only
    accepts the folders it models, and the fs test checks the missing case.
    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
2026-09-15 Add the APPS launcher as core/apps.prg
    A full-screen list of installed applications and games (name, version
    or GAME, description from app.json). RETURN ends it with
    UtilityResult(true, { run = path, kind = kind }) and the shell runs the
    choice, so a game still replaces the shell; ESC ends it with nothing.
    Moving the selection redraws two entries, scrolling the list. Living
    outside the shell, its list and code are in memory only while open.
    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
2026-09-15 Add chars (character set) and keys (input tester)
    - chars: the 256 ROM glyphs as a 16x16 grid with a cursor, the code in
    decimal/hex/binary, the glyph's name and the glyph in all eight
    colours plain and inverted (one Screen.OutAttrs for the colours).
    - keys: key-down log with code, name and modifiers, and live panels for
    joysticks 1 and 2 from Input callbacks; ESC twice or RUN/STOP quits.
    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
2026-09-15 Graphics SDK: sprites, rotation, text and shapes on the pixel modes
    A new framework for modes 10 and 11: Mode, PutPixel, Clear, Line,
    Rect/FillRect, Circle/FillCircle, Text/CenterText/TextWidth (8x8 font at
    1-4x with an optional background), Blit (split into bands past the op
    limit), Scroll/ScrollRect, RGB/Grey/Palette for the default 256-colour
    palette, Pixels (an image from ASCII art), Rotate (exact quarter turns,
    any angle by nearest neighbour into a square), Flip and Scale, and
    sprite objects with Draw/Hide/MoveTo/MoveBy/SetImage/Turn (rotated
    frames kept per angle), Overlaps and OnScreen, plus the 16 text colours
    by name. Rotation and scaling run in Lua when an image is built, so the
    di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
2026-09-15 Audio: pitch and tone effects, and a built-in bank of sounds
    Instruments gain the effects that make chip sounds: a pitch slide
    (semitones per second), vibrato (cents at a rate), a one-step or
    looping arpeggio (semitone steps every N ms) and a one-pole low-pass
    cutoff for tone, plus a note of their own. The pitch effects run at
    control rate (once per 64-frame block) from a cents table, so the mixer
    loop is unchanged. audio_presets.c is the ROM bank, baked in like the
    font: 16 instruments (lead, pulse, bass, piano, organ, strings, flute,
    brass, bell, pluck, chime, kick, snare, hihat, tom, clap) and 16 effects
    (coin, jump, laser, zap, explosion, hit, hurt, powerup, blip, select,
    error, alarm, e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
    [audio.h]
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2026-09-15 Add the sounds app; breakout and snake use the built-in effects
    sounds lists the bank with each sound's definition, plays a sound on
    RETURN (an instrument a fifth down or up on LEFT/RIGHT) and toggles a
    four-channel MML tune with M. Breakout's bounce, hit, hurt, powerup and
    per-row blip and snake's coin, powerup, explosion and teleport replace
    the hand-made tones.
    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
2026-09-15 Audio: a ProTracker MOD player streamed from the card, and sample loops
    mod.c plays 4-channel ProTracker modules without holding them in RAM:
    the header, order list and two patterns (the next prefetched, a jump's
    target loaded on demand) are resident, samples up to a 40 KB pool are
    kept whole (shortest first) and the long ones keep a 1 KB head so a
    note starts at once, then stream through a 4 KB ring per channel that
    core 1 refills ahead of the reader from the file (mod_service, every
    scheduler step) while core 0 runs the tick clock, the effects and the
    mixing inside audio_mix. Effects 0-9, A-F and E1/2/5/6/9/A/B/C/D/E;
    Amiga L-R-R-L panning, softened; channels mixed at 3/8 so a loud module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
    [audio.h, lua_main.c, mod.h]
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2026-09-15 sounds: D plays a bundled demo module
    resources/demo.mod is a small ProTracker module built from synthesized
    samples (bass, lead with arpeggio and vibrato, kick, hi-hat and a long
    looped pad that streams), so the player can be heard from the card.
    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
2026-09-15 sounds: a MODULES page playing the bundled .mod files
    TAB switches between the built-in sounds and the .mod files in the
    app's resources folder; RETURN streams the selected one from the card,
    SPACE stops it, and the panel shows the module's name, orders, patterns,
    samples, resident KB, underruns and the playing position. Six 4-channel
    M.K. modules (Entity, Flow, Industry, Modemulance, Orgasmod and demo)
    ship with the app; .gitignore's kernel-module rule no longer swallows
    them.
    The app is built stripped and without the Text framework to stay under
    the heap cap: 87 KB after setup on the host.
    Claude-Session: https://claude.ai/code/ses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
2026-09-15 IDE: vendor the simulator with the audio pump fix
    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
2026-09-15 sounds: SPITRACKER, a tracker view with a spectrum analyser
    The app becomes a module player in 80x60 text: a MODULES page lists
    the .mod files in its resources, RETURN plays one, and the TRACKER
    page shows the music: a ten-band analyser from Sound.Spectrum as
    half-cell bars with falling peak markers, a VU meter, note, sample,
    volume and sample name per channel from Music.ModChannels, the pattern
    scrolling past the row playing (Music.ModRows; a one-row advance is a
    region scroll plus three lines), the song position and the underrun
    count. SPACE stops and restarts, N/P and LEFT/RIGHT skip modules, TAB
    and F1 switch pages; the built-in sound bank stays as the SOUNDS page.
    Every visual redraws o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
